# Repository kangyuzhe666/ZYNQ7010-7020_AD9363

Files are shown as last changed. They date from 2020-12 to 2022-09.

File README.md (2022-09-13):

# ZYNQ7010/7020_AD9363/AD9364/AD9361

####  Open source SDR hardware based on ZYNQ+AD936X






[中文](./README_CN.md) 
##  Open source SDR hardware based on ZYNQ+AD936X

## The preliminary development work has been completed and the product has entered the trial production stage. Please contact the email address: 1399109998@qq.com for finished products.
2022-09-13 update
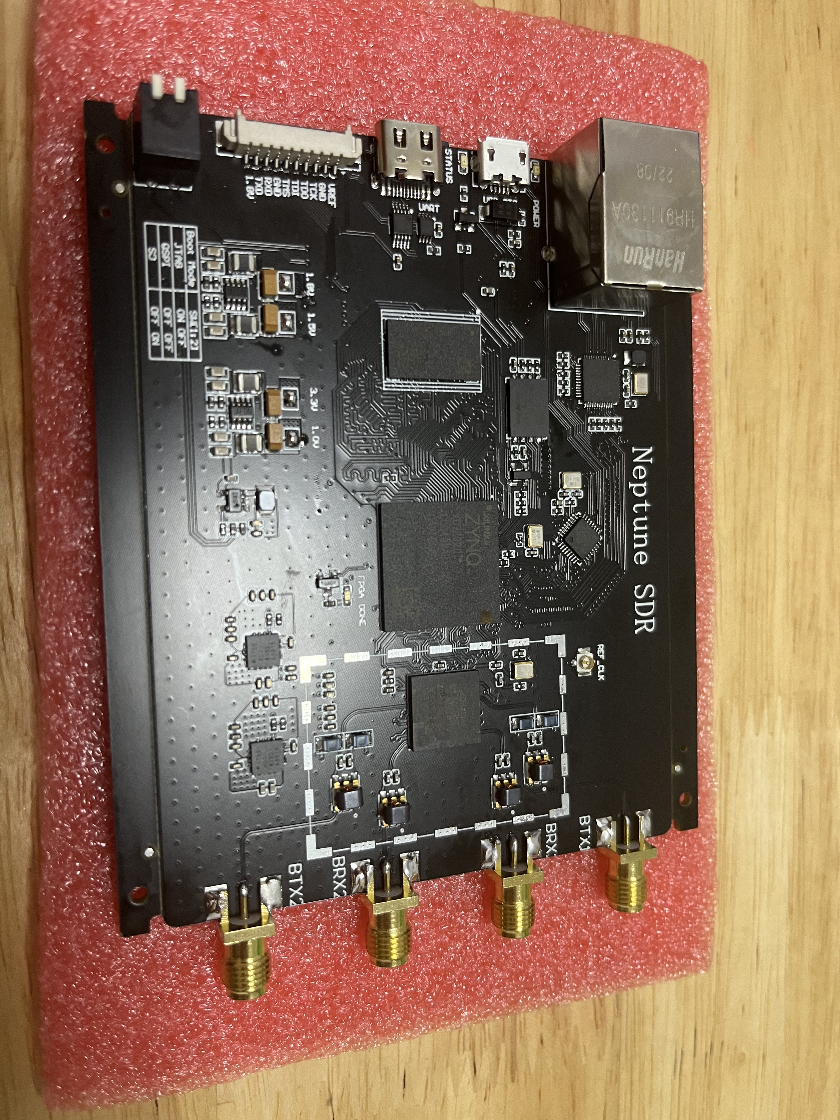
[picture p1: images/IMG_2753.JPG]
a83

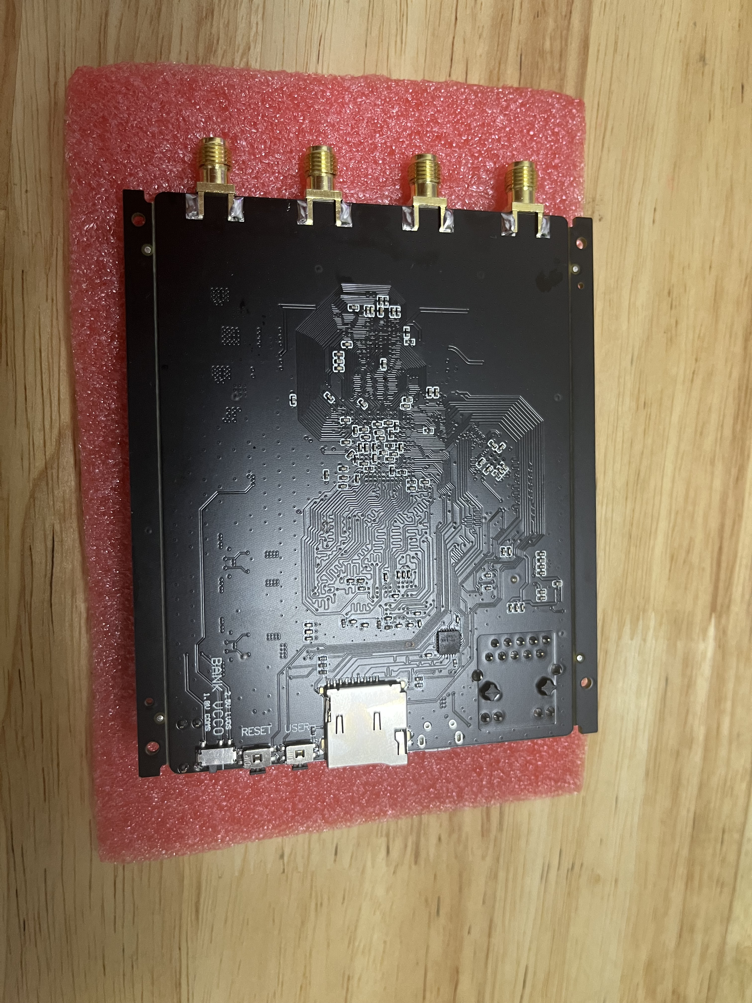
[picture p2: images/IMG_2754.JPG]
a82

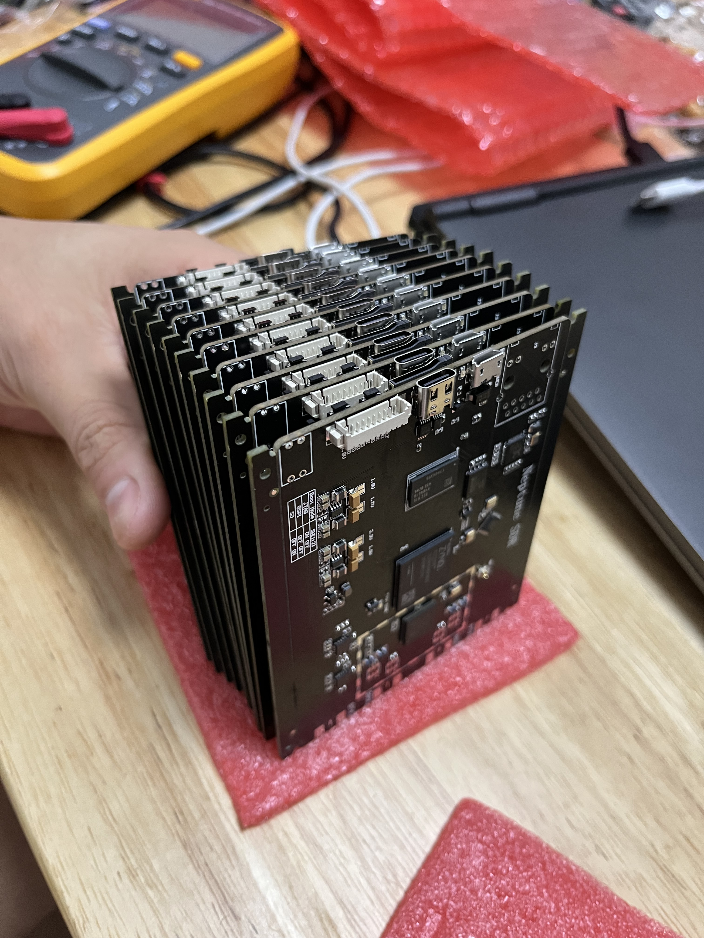
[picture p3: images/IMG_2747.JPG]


## formal support openwifi
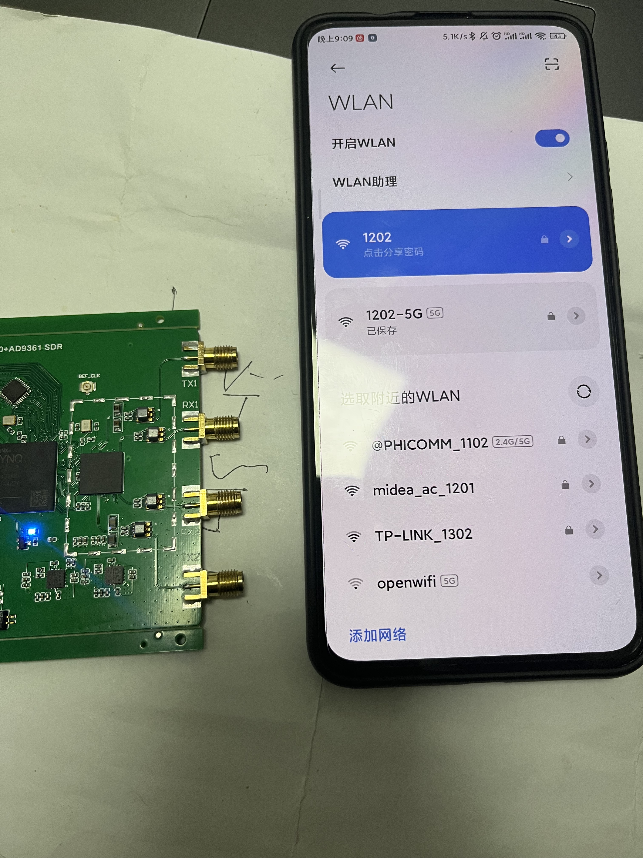
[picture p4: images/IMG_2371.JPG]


openwifi test video
- https://www.bilibili.com/video/BV1hB4y1k7dm?spm_id_from=333.999.list.card_archive.click

Project introduction video:

- https://www.youtube.com/watch?v=Qk-M8yRsKvs 

- https://www.youtube.com/watch?v=xx4MXQSHmCM&t=153s

GSM signals receiver test:
- https://www.youtube.com/watch?v=yFEpSrWW0-w

FM signal receiver test:
- https://www.youtube.com/watch?v=ASb7dLIEmfY

Sine wave signal transmission test:
- https://www.youtube.com/watch?v=bfs_GfULIoA&t=55s

Loopback signal test:
- https://www.youtube.com/watch?v=JOjsKboq0xA

The pluto-sdr firmware transplantation work is all done, flashing the firmware without hacking the system, the default is AD9364.

#### 1. Hardware solution

FPGA: ZYNQ7010/7020 (ZYNQ7010 and ZYNQ7020 can be replaced with each other, if you need more hardware resources, please use ZYNQ7020)

RF: AD9361/AD9363/AD9364 (the three chips can be replaced with each other, the difference lies in the bandwidth. Among them, AD9361 has better performance, try to use the ABCZ ending chip, which is different from BBCZ)

https://ez.analog.com/wide-band-rf-transceivers/design-support/f/q-a/80027/what-is-difference-of-ad9363-abcz-and-bbcz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

AD9363ABCZ Band: 325 MHz to 3.8 GHz

AD9363BBCZ Band: 650 MHz to 2.7 GHz

RAM Memory: DDR3 256M16

USB-PHY: USB3320C

GMAC-PHY: RTL8211E-VL (RTL8211E has two endings, VB and VL, where VB level is 3.3V/2.5V, VL is 1.8V)

QSPI FLASH: W25Q256 32MB

Power supply topology diagram

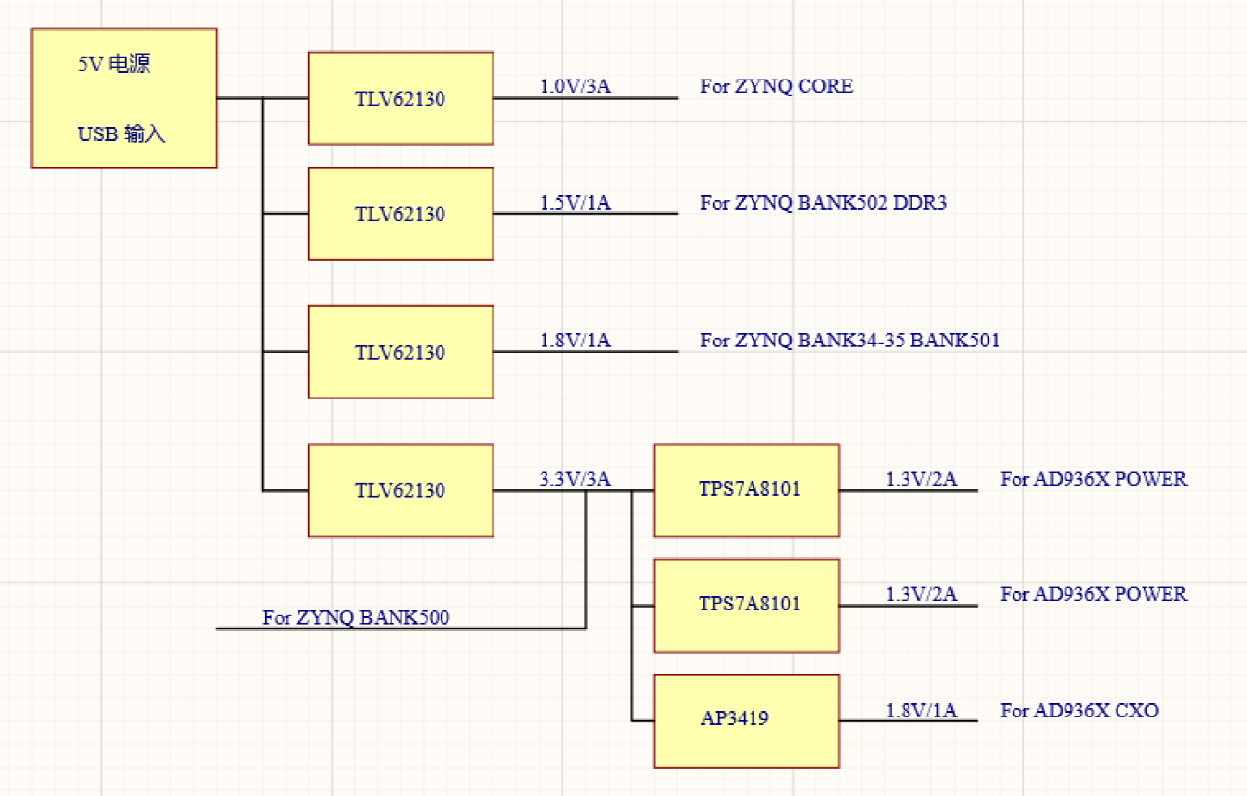
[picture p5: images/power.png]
power


block design

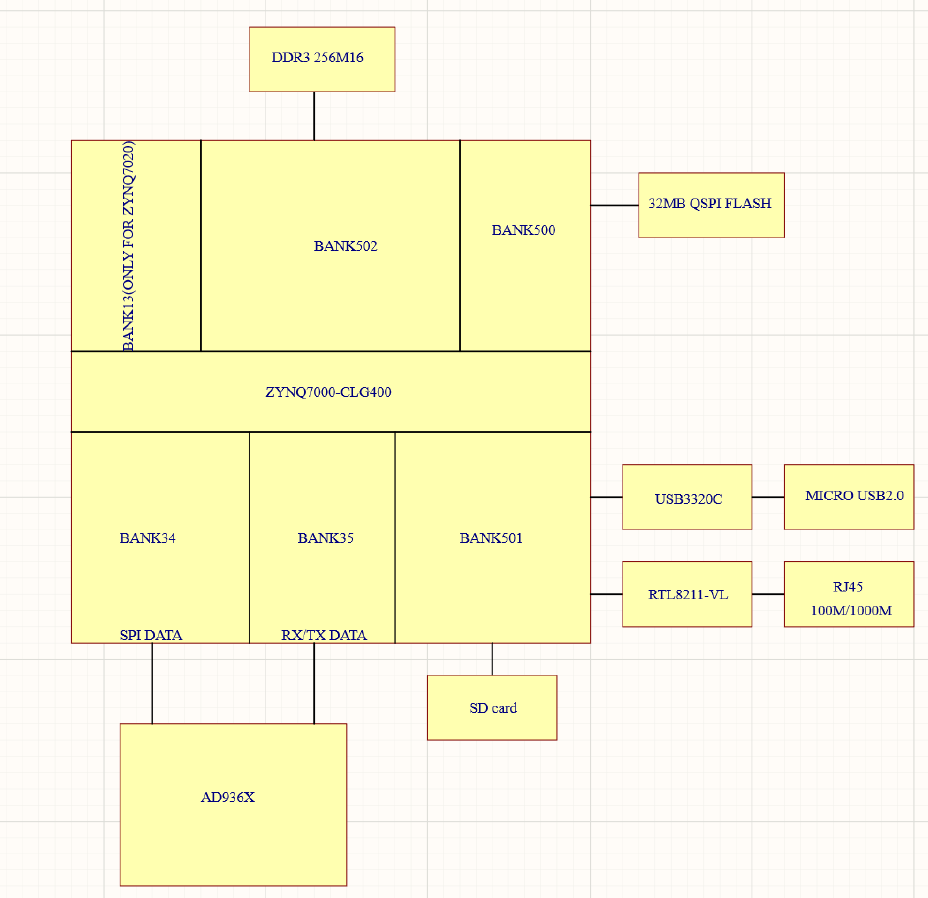
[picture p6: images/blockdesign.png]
blockdesign


##### 2. Software resources

Support Pluto-SDR firmware transplantation, OpenWiFi (ZYNQ7020 FPGA required), support adi official ZED+AD-FMCOMMS2/3/4 related firmware code

#### 3. PCB board design

Design software:  Altium Designer Kicad

Number of layers: 4 layers （signal layer[1]、GND[2]、POWER[3]、signal layer[4]）

Craft: JLC PCB Craft

Impedance: not supported

The impedance version will be tested in March 2021, and the openwifi port is currently undergoing normal transceiver tests.

#### 4. Differences compared to ADALM-PLUTO:

- Support for Zynq-7020 and Zynq-7010 in 400pin BGA package
- Support 2R2T transceiver mode
- 4 layer board to reduce cost
- SD slot for running real Linux distros
- Support Gigabit Ethernet

#### 5. Project display:

This is the PCB rendering

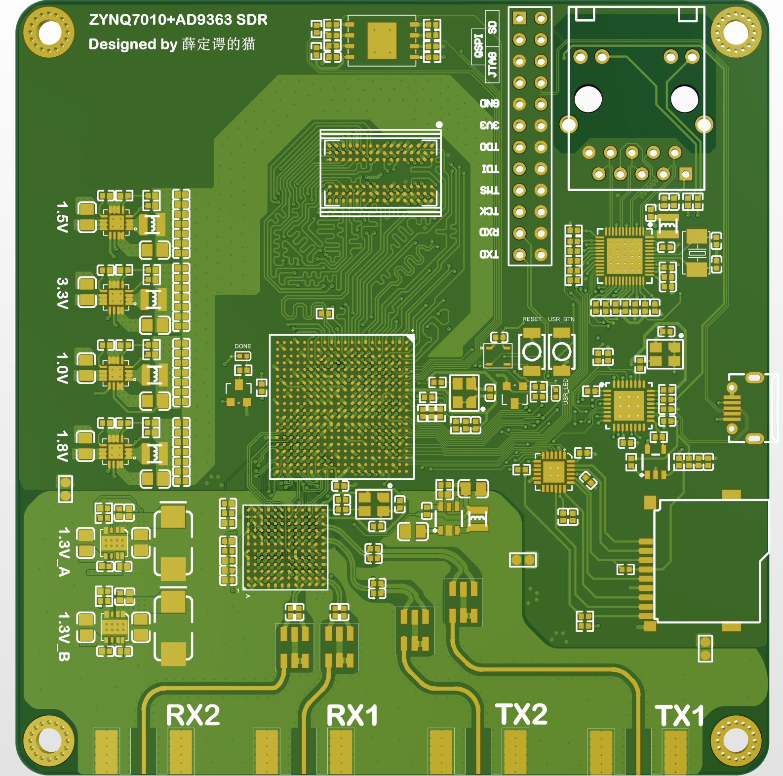
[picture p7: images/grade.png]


This is the physical picture of the PCB

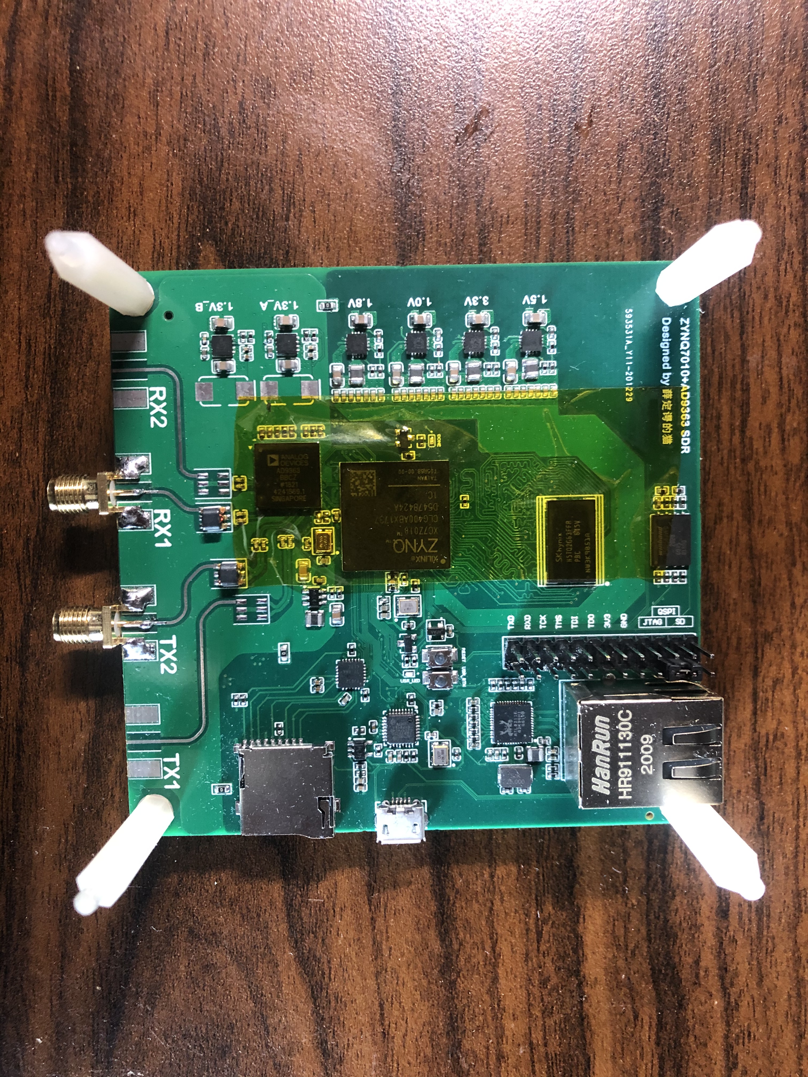
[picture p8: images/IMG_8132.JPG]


This is the details of the PCB RF part

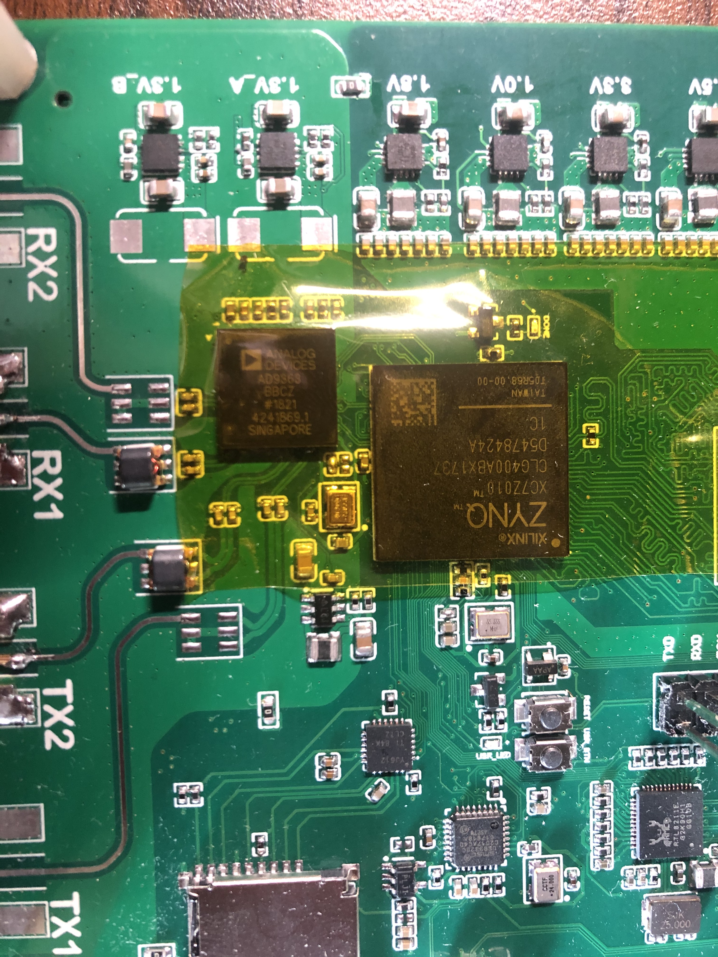
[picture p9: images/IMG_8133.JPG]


Ethernet can work stably at 1000M (using single-arm routing for testing in the figure)

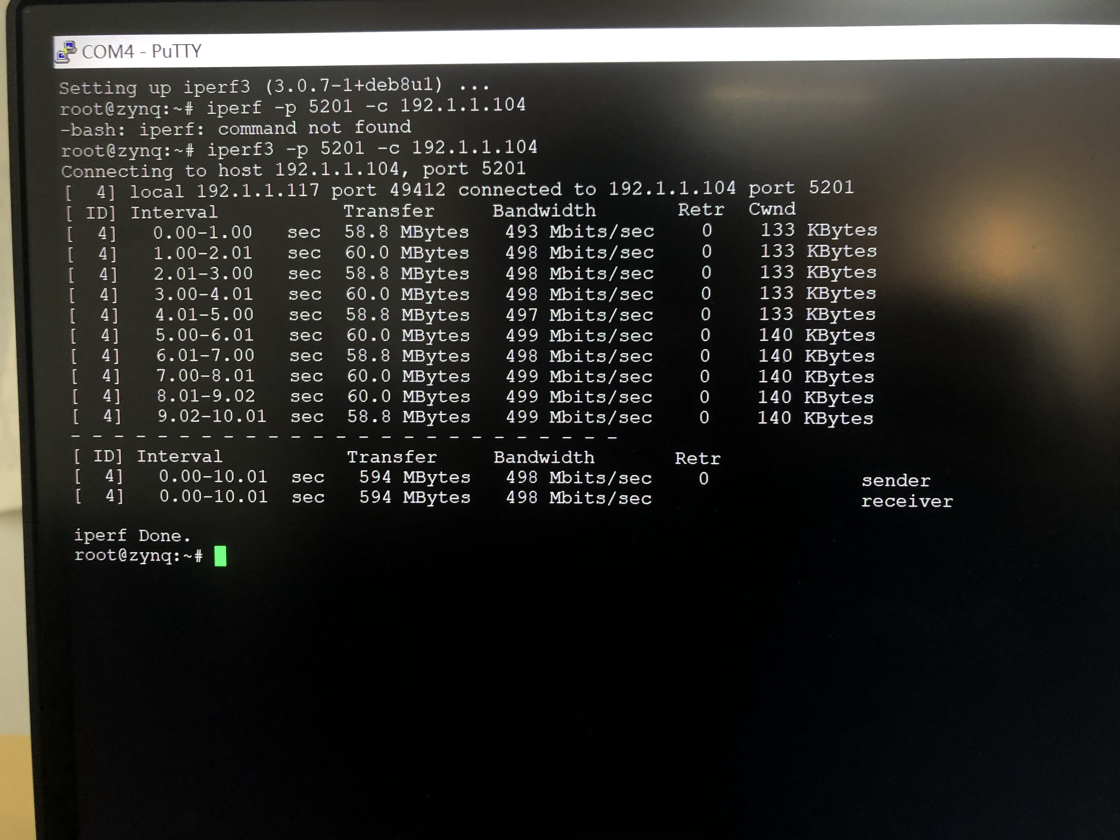
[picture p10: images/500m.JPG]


AD9363 initializes the normal graph using adi no-os test environment

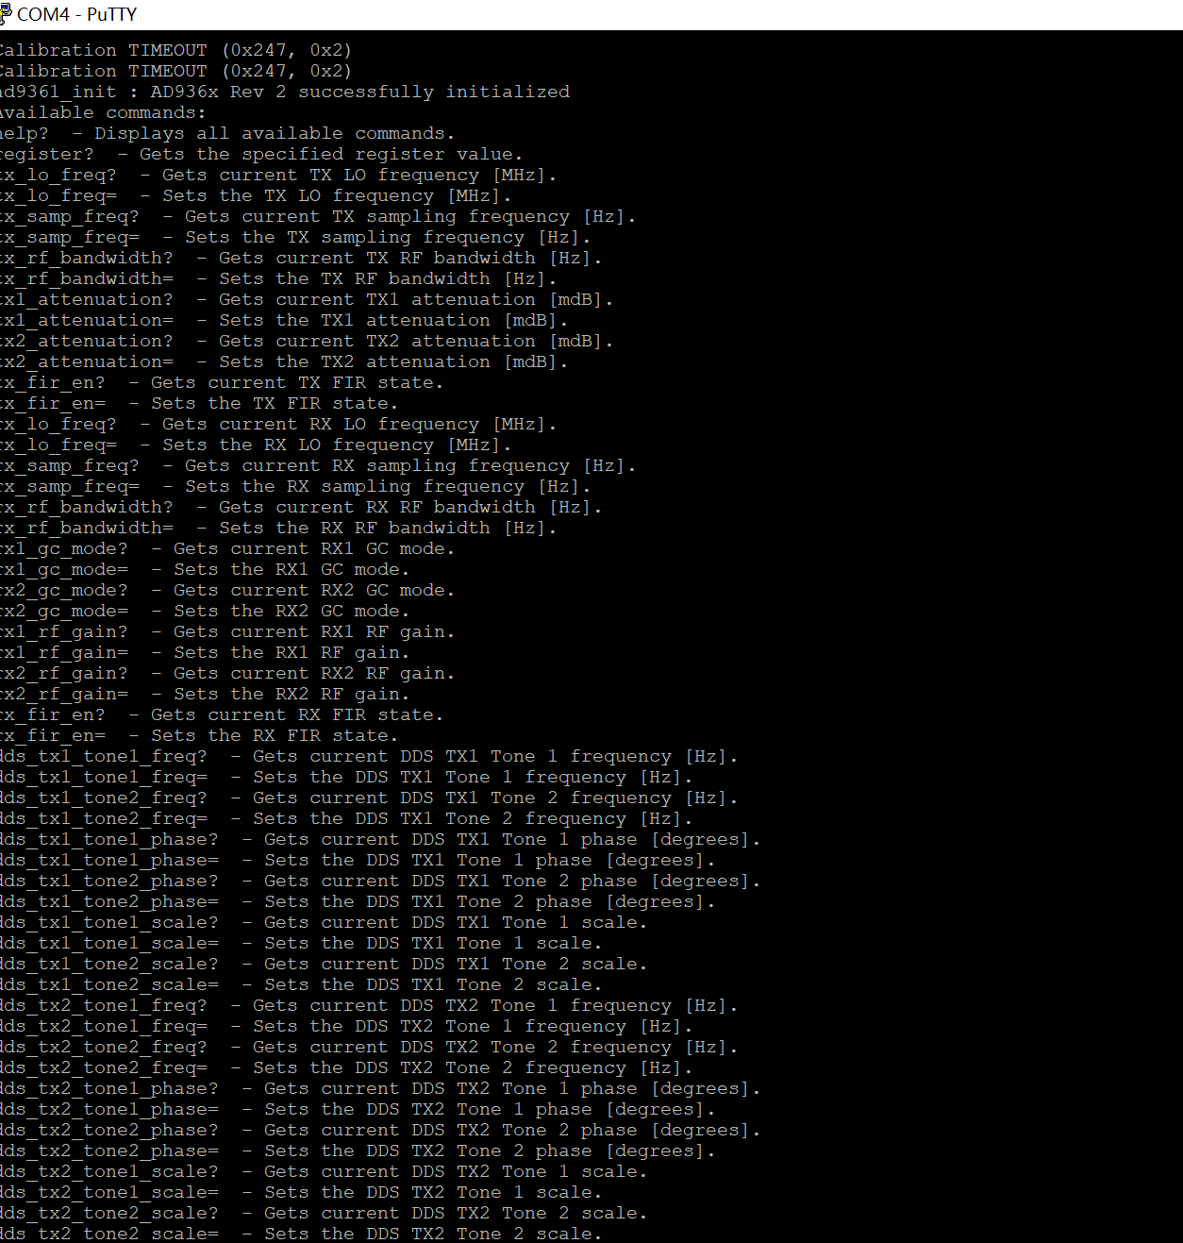
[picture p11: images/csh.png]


Pluto-uboot transplanted successfully

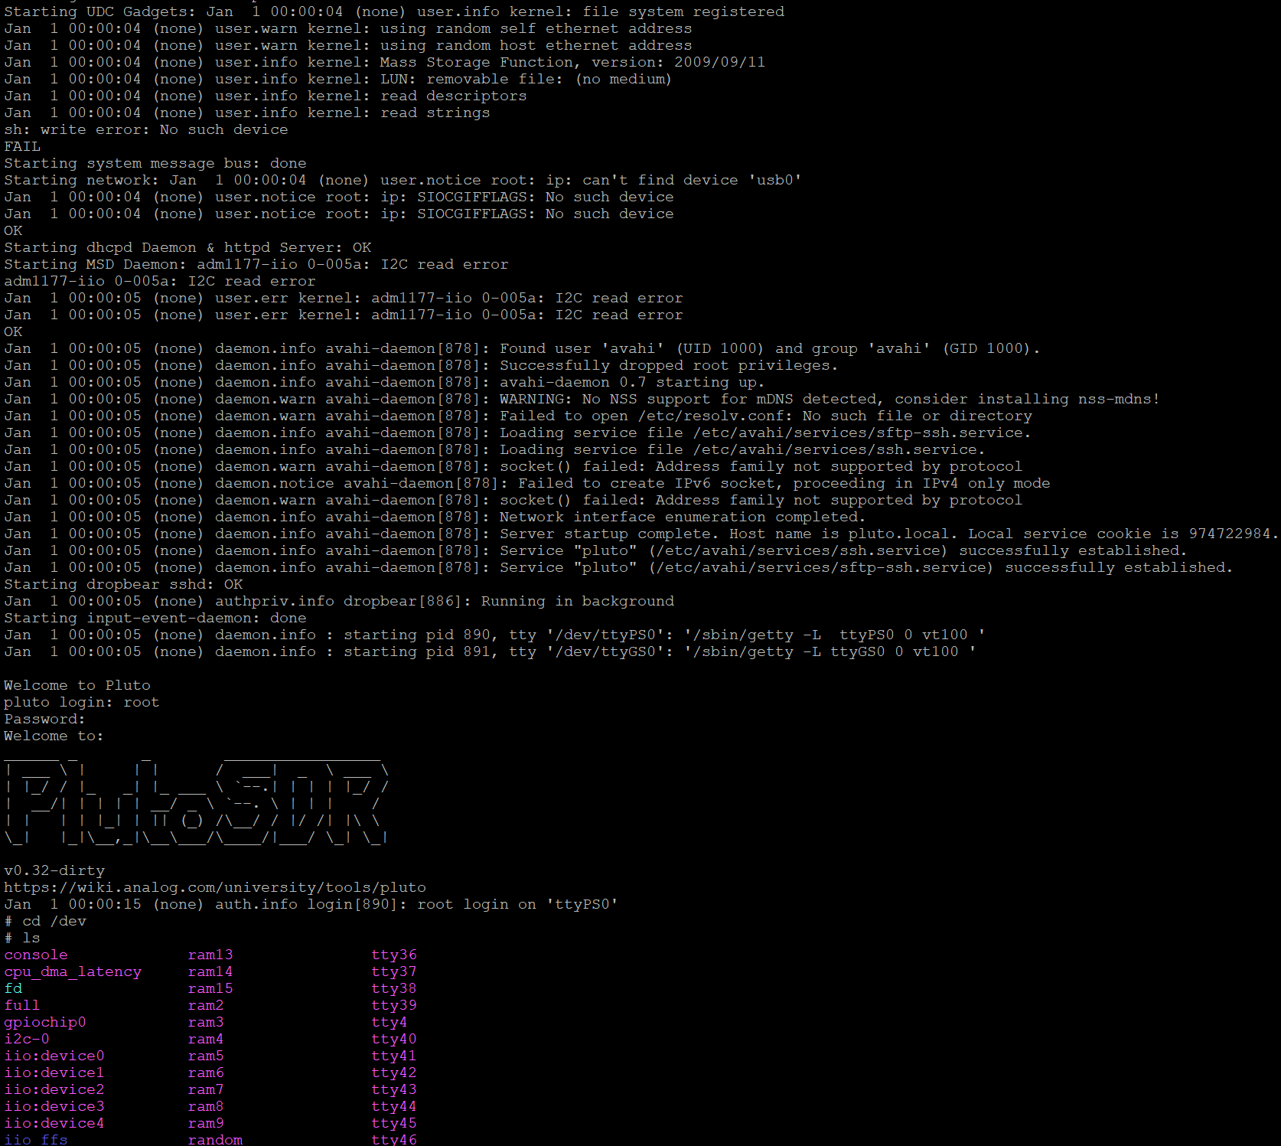
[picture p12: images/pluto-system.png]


Pluto firmware works fine

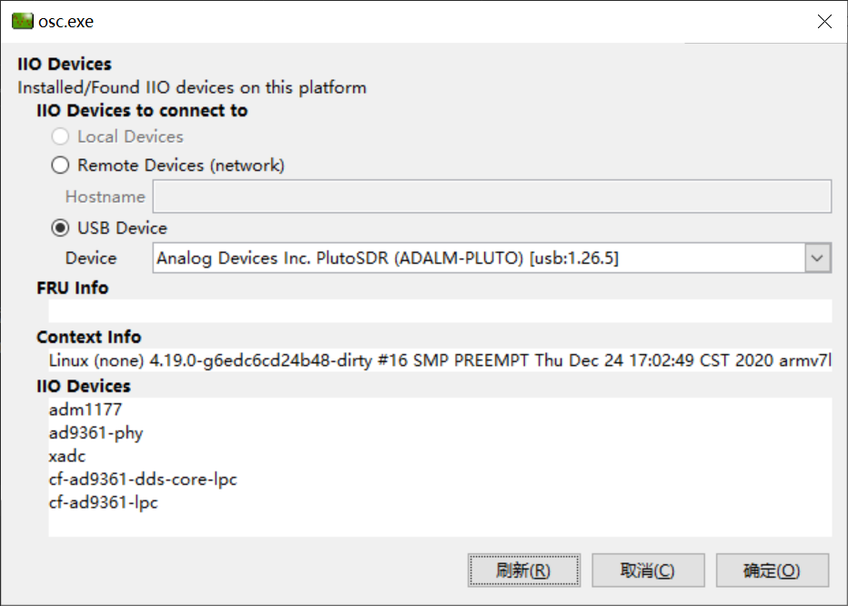
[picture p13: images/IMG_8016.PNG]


Receive GSM signal normally

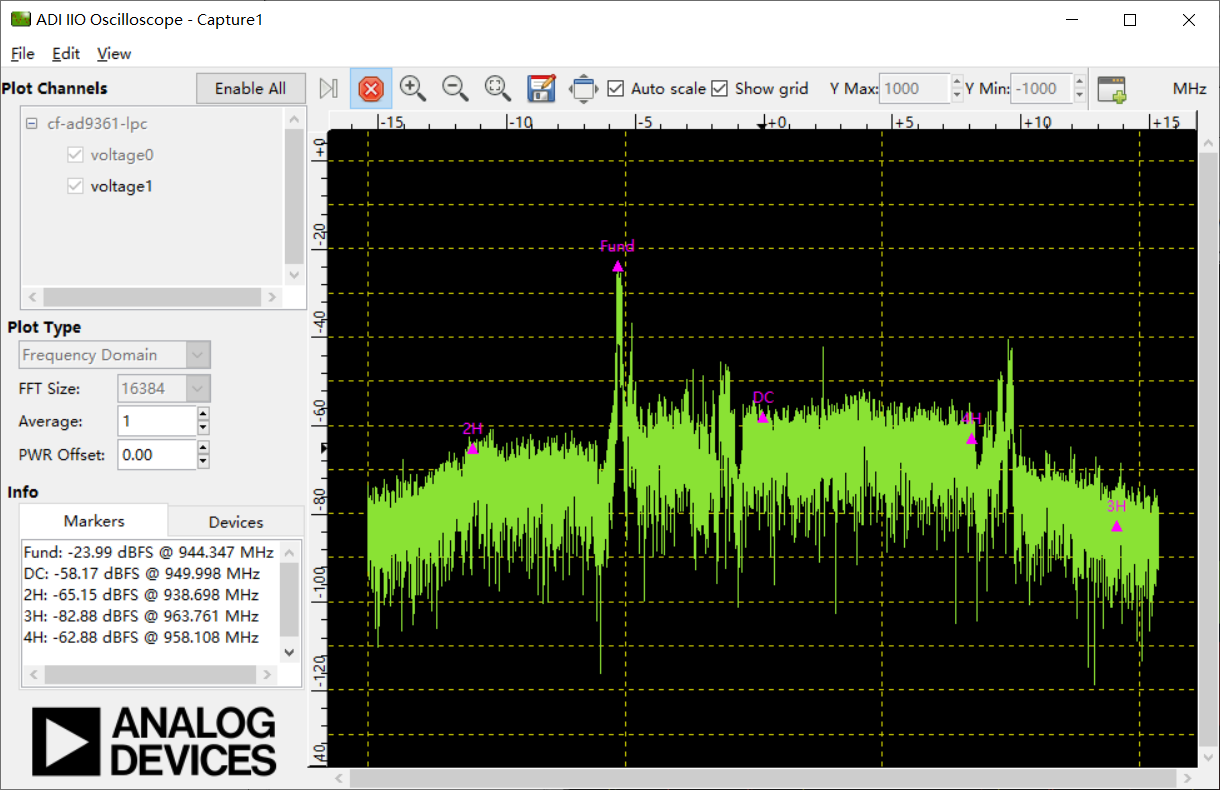
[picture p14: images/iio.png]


Hack into AD9364 to receive FM signal

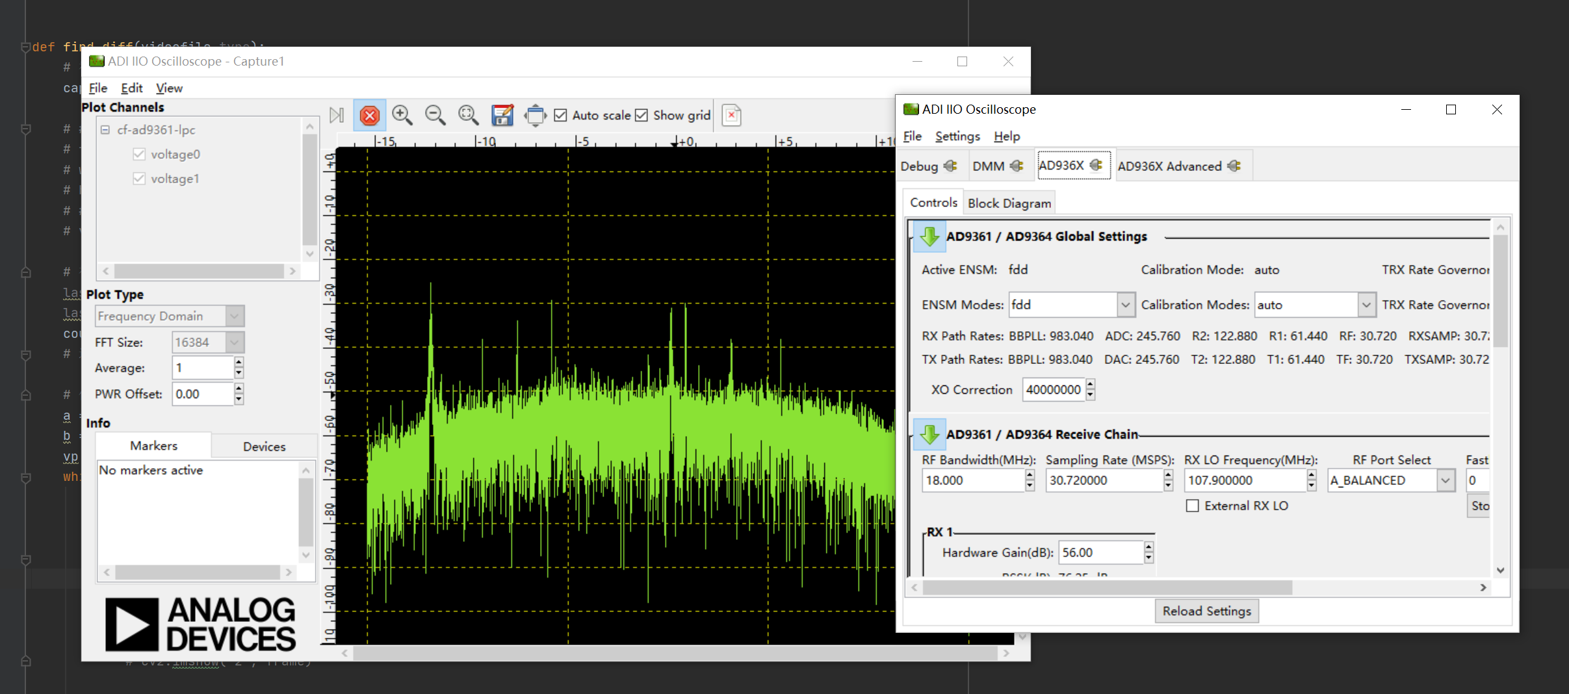
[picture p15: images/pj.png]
pj


Two PCBAs receive and send each other test

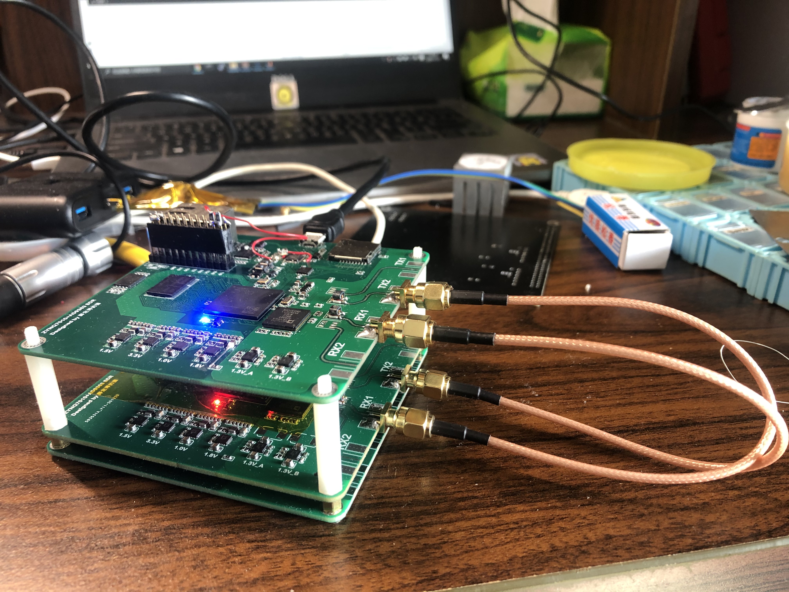
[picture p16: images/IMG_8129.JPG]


PCBAs can be stacked on each other and connected through Gigabit switches and routers

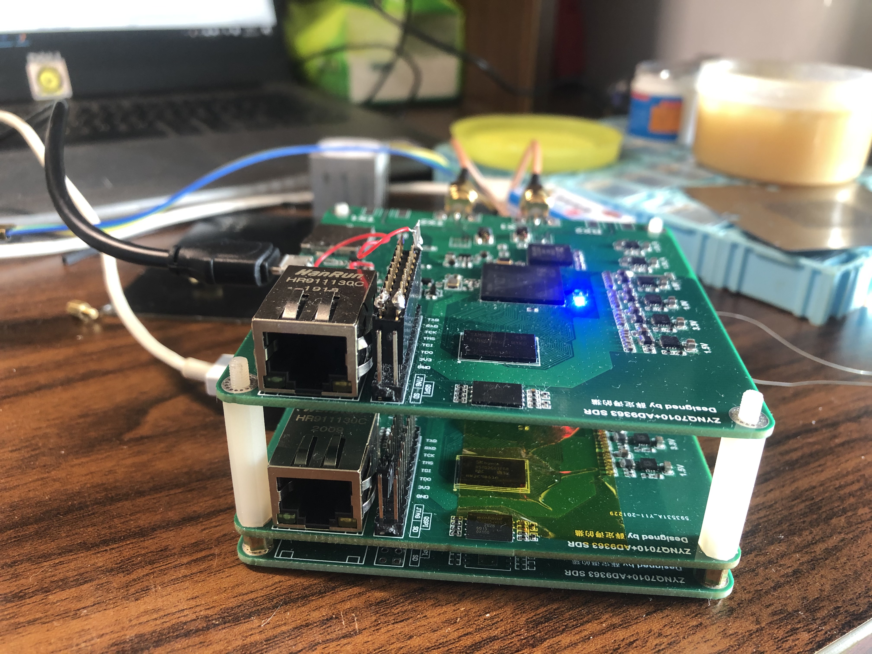
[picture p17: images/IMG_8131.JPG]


Support SDR-SHARP

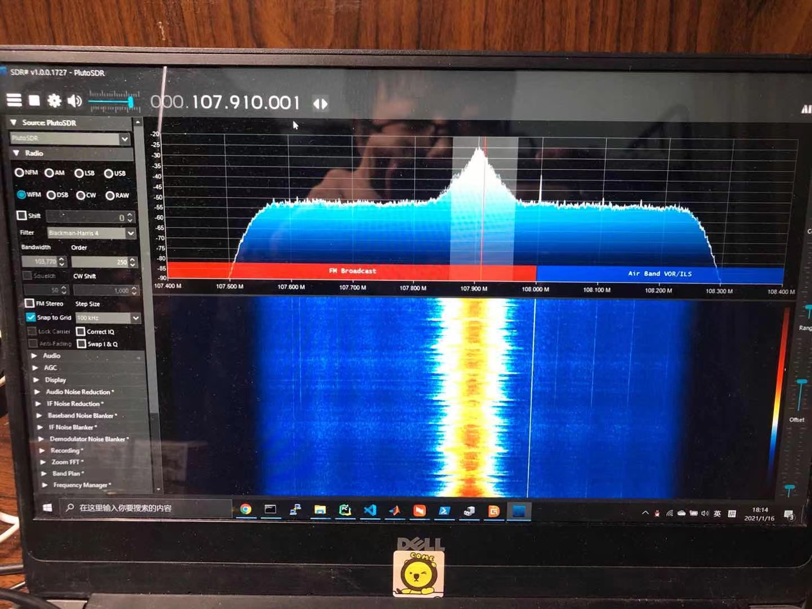
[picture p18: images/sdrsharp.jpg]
sdrsharp


##### 6.TO DO LIST

- Continue to optimize the RF part to reach the adi official demo board indicators
- Impedance design based on four-layer pcb
- To be completed in January-February of 2021, to complete the relevant transplantation work of openwifi
- Design the impedance version in March 2021
- Conduct commercial index tests on the impedance version in April 2021
- When the commercial version is launched at the end of April 2021, it will support adi's official SDR firmware (ADRV9364 packet), openwifi, and openbts openbts, etc.

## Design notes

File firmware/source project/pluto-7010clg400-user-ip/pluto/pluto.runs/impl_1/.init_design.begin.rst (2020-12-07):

<?xml version="1.0"?>
<ProcessHandle Version="1" Minor="0">
    <Process Command=".planAhead." Owner="kyz" Host="" Pid="129447">
    </Process>
</ProcessHandle>

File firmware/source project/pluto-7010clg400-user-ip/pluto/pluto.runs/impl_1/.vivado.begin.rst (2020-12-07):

<?xml version="1.0"?>
<ProcessHandle Version="1" Minor="0">
    <Process Command="vivado" Owner="kyz" Host="" Pid="129406">
    </Process>
</ProcessHandle>

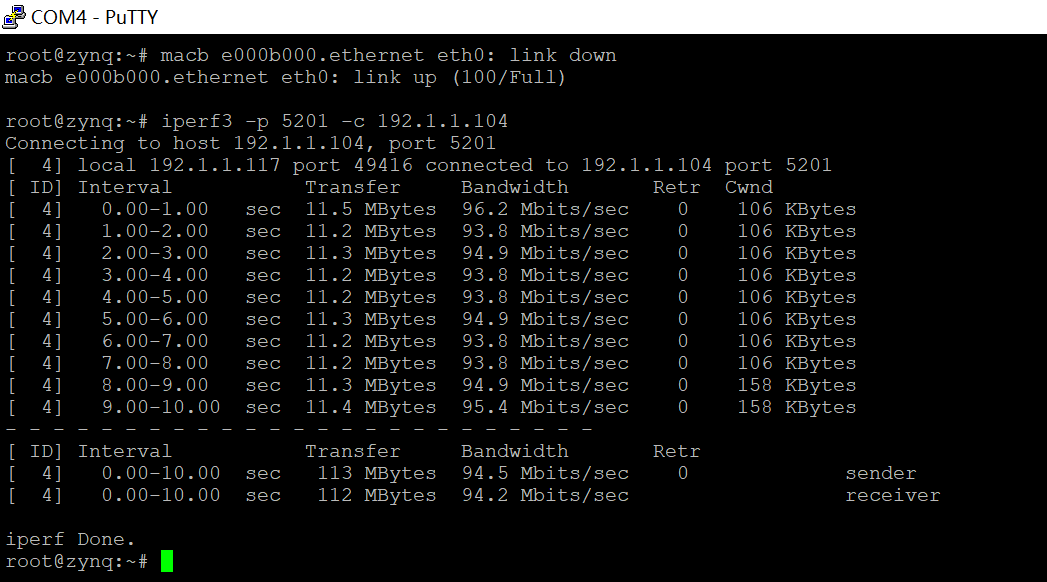
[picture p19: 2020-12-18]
images/eth.png

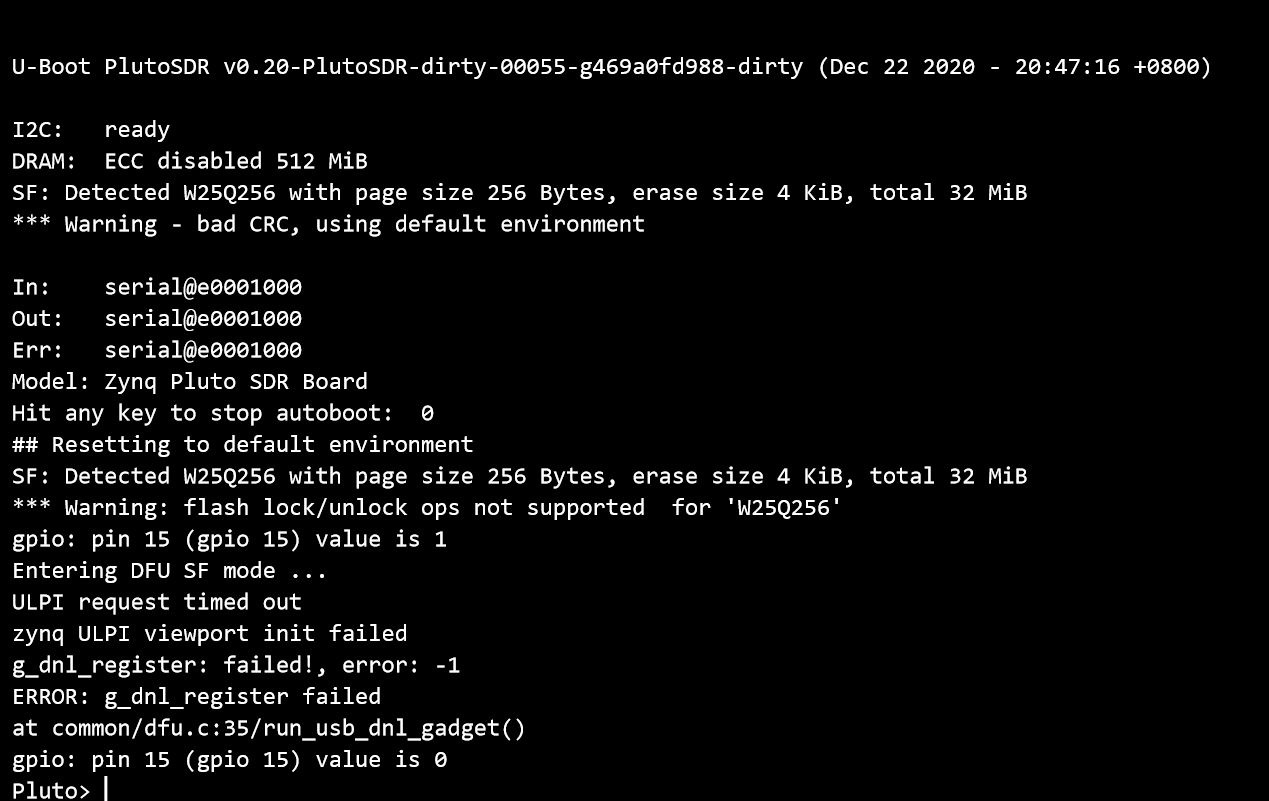
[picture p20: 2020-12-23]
images/pluto.png

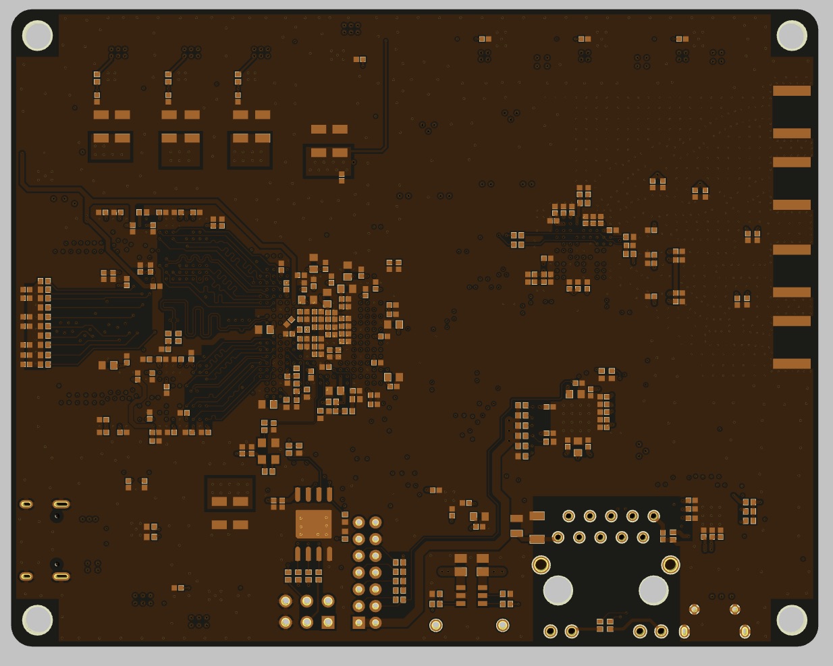
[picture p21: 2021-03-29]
images/a81.PNG

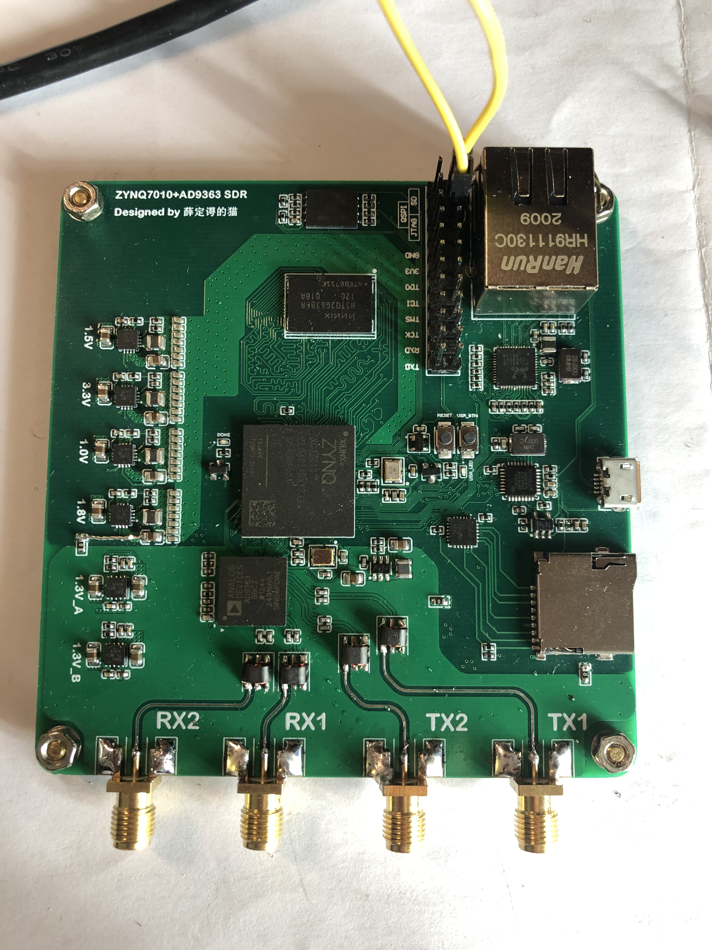
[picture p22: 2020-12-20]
images/wq.JPG

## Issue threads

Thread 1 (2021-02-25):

Max sample rate?

eljuligallego, 2021-02-25:
Hello,
congratulation for the amazing work it looks amazing.

I'm just curious about this because is picture of max transfer with iperf3 you get more or less 95Mbits but it is because the ethernet is configured as 100mbps but the ethernet chip could handle 1gbps.

Also from other pluto-like board with ethernet they stated the bottleneck is in the iio driver but 10Msps could be achieved and from analog specification(2 bytes per sample and IQ baseband) this is about 320mbps. Also the pluto board could get 24MBps with usb2 because usb bottleneck.

it's possible to get gigabit ethernet or is still in progress?.

Thanks,
juli.

kangyuzhe666, 2021-02-26:
Hello, thank you very much for your interest in my project. At present, the development of eth for this project has been completed. Theoretically, it can reach a sampling rate of 19msps (occupying about 700-800mbps bandwidth, please use gigabit link equipment). This project uses rtl8211e to automatically negotiate as a 1000m Ethernet in the system. The relevant firmware has been released [https://github.com/kangyuzhe666/ZYNQ7010-7020_AD9363/releases]
At present, we are further improving the stability of the hardware, and a stable hardware version will be launched in March. At that time, the price of the hardware will be much lower than the same pluto hardware with eth on the market.

Thanks,
yuzhe Kang

eljuligallego, 2021-02-26:
Thanks and please let me know if you get to capture with this throughput 800mbps, no much sdr board can do this, but as far I can understand form the pluto+ creator who just import the pluto firmware to its board(and he uses the same rtl8211 chip):

https://twitter.com/fei666888/status/1354228737491890178

"At present, when the test reaches 10M bandwidth, it will be stuck, which is far from full of Ethernet bandwidth. We analyzed the reason is that ADI's IIO drive efficiency is too low, and time is spent on memory copying."

kangyuzhe666, 2021-02-26:
Hello, thank you very much for your reply. I am not sure about this developer's firmware development on Twitter. ZYNQ7000 has two ARM A9 cores. It can only be limited to about 10M when using one core. The official firmware of pluto only turns on one core by default. Our project uses two A9 cores, so it can meet the sampling rate above 10M, please continue to pay attention to my github dynamics. We will upload more test data in the future. Since I am currently on holiday, I cannot provide too much data to you. Please wait for a while.

eljuligallego, 2021-02-26:
Thanks for your attention.I will stay on tune.

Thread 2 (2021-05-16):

sd card

hitstm32, 2021-05-16:

hitstm32, 2021-05-16:
use for voltage trans?

kangyuzhe666, 2021-05-18:
> use for voltage trans?
Since the signal level of most sd cards is 3.3v, and the io level of bank501 connected to the sd card is 1.8v, in order to make the sd card work normally, txs02612 is added for level conversion

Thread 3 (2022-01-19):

PCB update

mihaly4, 2022-01-19:
Hello,
Are you planning to update PCB files in this repo to latest versions, seen on images?

LavanyaPriya23, 2024-11-27:
Hello,
Can you provide fab notes for the pcb design?

LIMPIX31, 2024-12-21:
Also want to see the updated kicad files to use as a reference in my design

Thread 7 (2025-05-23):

Help, the whole board has no response after power on

X-System-U, 2025-05-23:
After powering on via USB, the tps2051 was not turned on, resulting in a lack of power to the entire board. The voltage between pin 24 and pin 22 of the usb3320 was only 2.1v. I think this may be the reason why the usb3320 did not send a high-level start signal to the tps2051. However, the components were installed according to the schematic diagram. Currently, only the zynq7010 ad9363 and the flash memory chip were not installed.Hope to answer

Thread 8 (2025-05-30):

RFGND resistors vs. ferrite beads & RF Shielding possibilities

Wilmox, 2025-05-30:
Hi! Thank you for making this beautiful open-source SDR!

I am wondering why you have so many **0-Ohm** resistors going from **RFGND** to **GND** (RX6-RX8 & RX13-RX15 in AD9363.SchDoc)? Are these supposed to be placeholders for Ferride beads to minimize high-frequencies going to GND, or are you really soldering **0 Ohms** on them?

The same applies to RX4 (same schematic); is this a placeholder for a **pull-up resistor** or **ferrite bead**? Or also **0 Ohm**?

Last quick question: Do you have a recommended **RF shield** to mitigate any electromagnetic interference coming out of the **AD9363** or the transformers close to it?

Looking forward to any answers!

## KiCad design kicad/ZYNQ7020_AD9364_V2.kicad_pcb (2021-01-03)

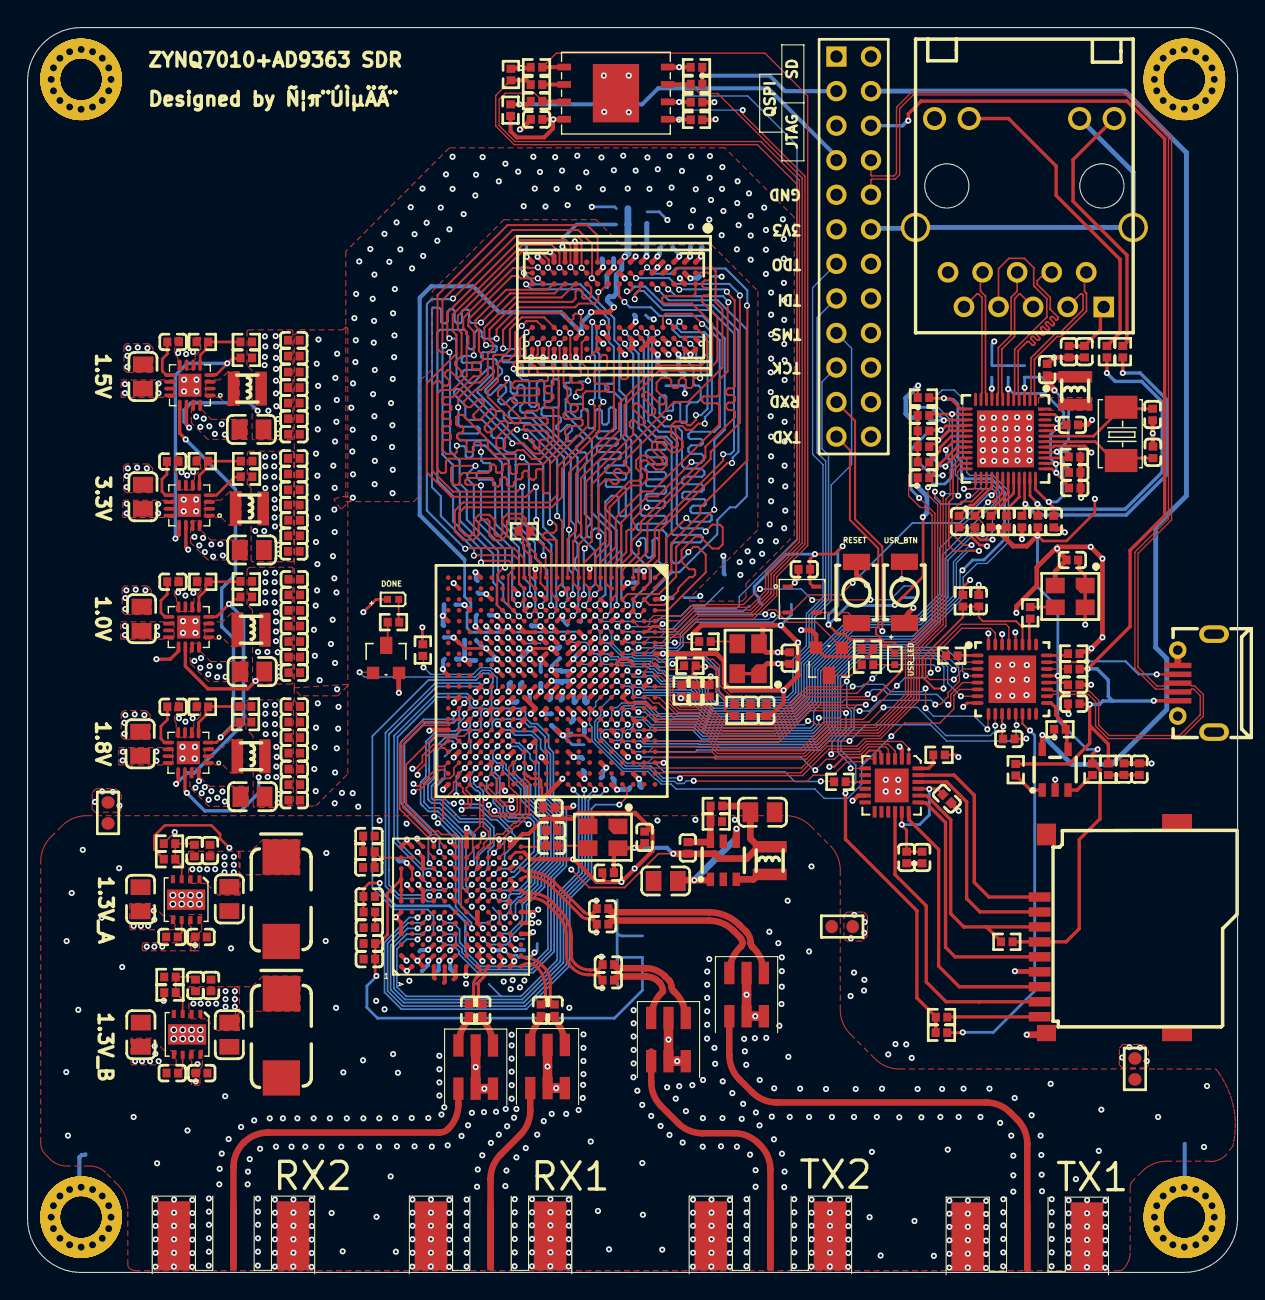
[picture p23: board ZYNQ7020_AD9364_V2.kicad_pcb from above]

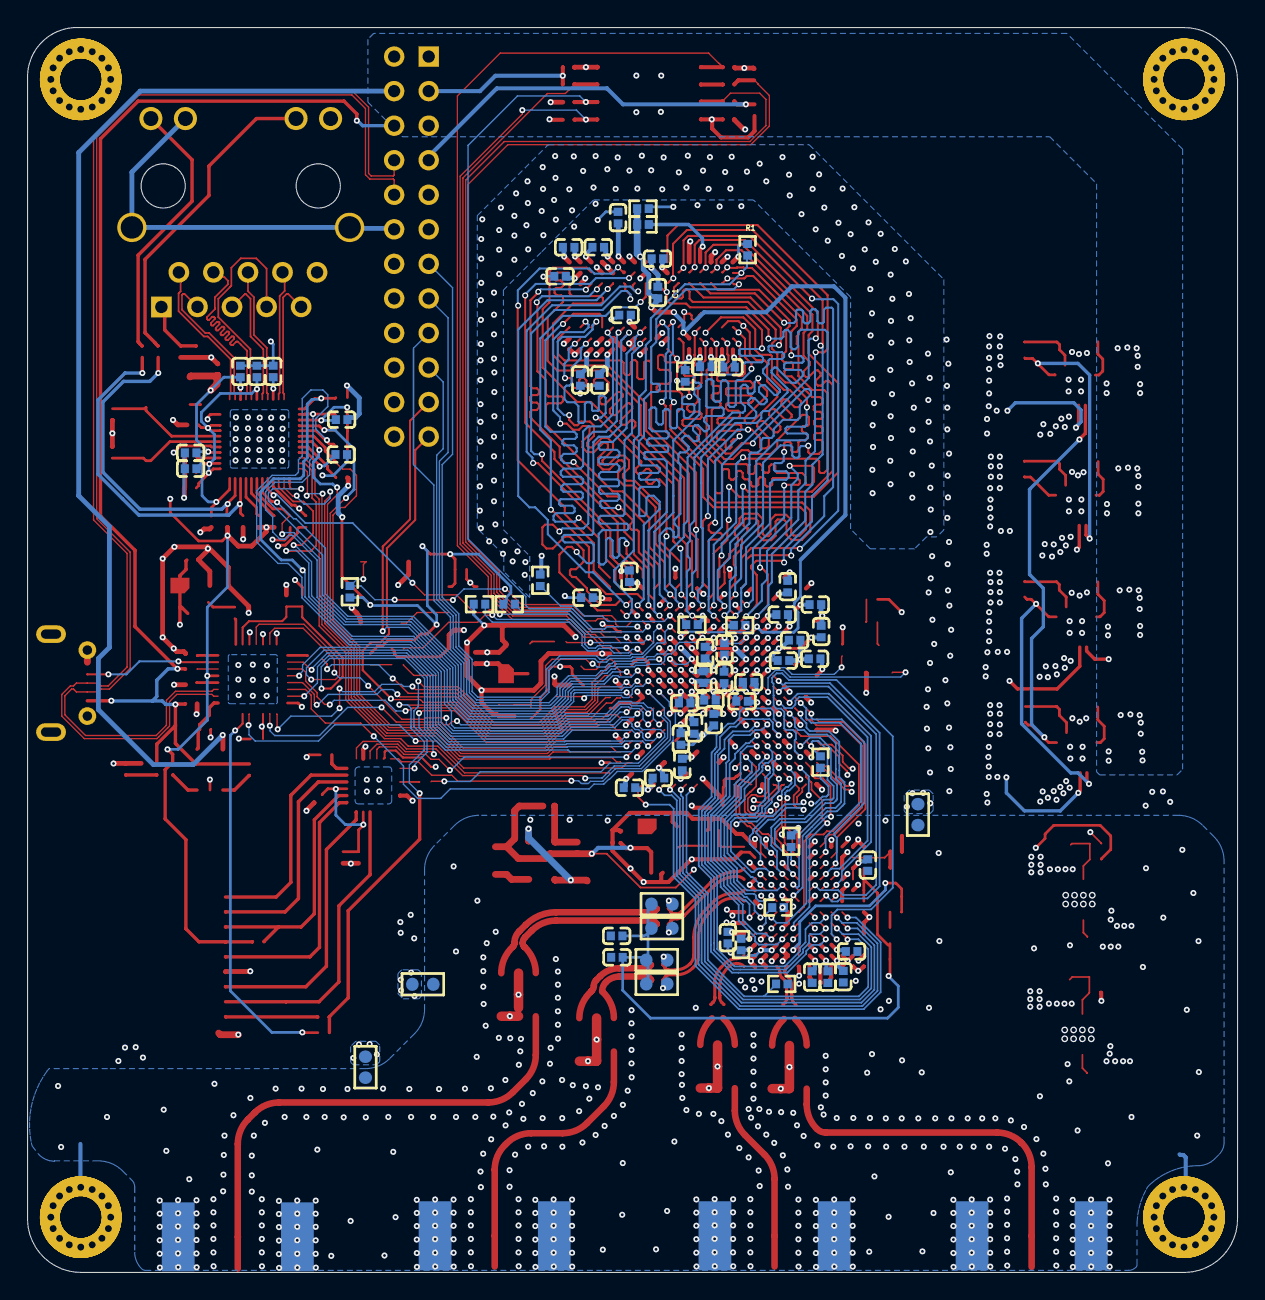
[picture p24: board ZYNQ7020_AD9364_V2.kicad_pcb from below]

Board: 4 copper layers, 89.0 x 91.5 mm, 287 parts (71 on the bottom side), 278 nets.

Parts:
*: W25Q128
C1, C159, C160, C161, C187, C188, C189, C190, C191, C192, C193: 104; CAP
C2, C3, C4, C5, C8, C9, C10, C12, C33, C34, C35, C36, C37, C38, C39, C49, C50, C51, C52, C53, C57, C61, C62, C67, C68, C69, C70, C71, C72, C73, C74, C75, C76, C77, C78, C80, C81, C82, C83, C85, C86, C87, C89, C90, C91, C96, C98, C99, C100, C101, C102, C103, C104, C105, C106, C107, C108, C148, C149, C181, C182, C183: 10¦ÌF; CAP_3
C6, C7, C11, C13, C18, C21, C23, C26, C27, C28: 0.1¦ÌF; CAP_3
C16, C29, C30, C31, C32, C40, C47, C48, C117, C118, C150, C152: 18p; CAP_1
C17, C20, C22, C25: 2.2¦ÌF; CAP_3
C19, C24: 3.3nF; CAP_3
C58, C60, C121, C139, C144: 10¦Ì; CAP_2
C59, C63: 0.001¦Ì; CAP_2
C109, C110, C111, C113, C114, C115, C116, C124, C125, C126, C127, C128, C130, C131, C142: 1¦Ì; CAP_2
C112, C120, C122, C132, C133, C134, C138, C141, C143: 0.1¦Ì; CAP_2
C119: 0.01¦Ì; CAP_2
C129, C135, C136, C137: 4.7¦Ì; CAP_2
C145, C166, C170, C172, C174: 1¦Ì; CAP_1
C146, C151, C175, C177: 0.001¦Ì; CAP_1
CP1, CP3: 22uF; CAP_1
CP2: 22pF; CAP_2
Ct1, Ct2: 3.3nF; CAP_3_3
DONE: LED; LED0
J2: microusb
L1, L2, L3, L4, L6: 2.2uH; INDUCTANCE_1
L5, L7, L8, L9: 330nh; INDUCTANCE
LG1: HR911130C
LP1: 4.7uH; INDUCTANCE
P2: Header 12X2A
Q1, Q2: AO3400
R1, R4, R5, R27, R35, R36, R38, R39, R40, R41, R43, R45, R46, R55, R57, R62, R63: 4.7K; RES
R2, R3: 82R; RES
R6: 240R; RES
R7, R68: 100K; RES
R8, R13, R15, R19, R24, R25, R30, R54, R65, R69, R71: 10K; RES
R9: 4.99K; RES
R10: 18.7K; RES
R11, R47, R49, R50, R51, R52, R53, R56: 20K; RES
R12, R17: 15K; RES
R14: 13K; RES
R16: 56.2K; RES
R18: 18K; RES
R20: 80.6R; RES
R21, R22: 6.25K; RES
R23, R64, R67: 0R; RES
R26: 2.49K; RES
R28, R29, R37, R42, R58, R76: 33R; RES
R31, R32, R70: 330R; RES
R33, R34: 1.5K; RES
R44: 8.06K; RES
R48, R66: 1K; RES
R59, R60, R61: 470R; RES
R72: 40.2R; RES
R73, R74: 1R; RES_1
R75: 14.3K; RES_1
RESET: SW-PB
RP1: 10K; RES_1
RP2: 20K; RES_1
RX1, RX2: JCCEM001
RX4, RX5, RX6, RX7, RX8, RX10, RX13, RX14, RX15, RX22: 0R; RES_1
T1, T2, T3, T4: TCM1-63AX+
TU1: TPS2051BDBVR
TX1, TX2: JCCEM001
U1: XC7Z010-CLG400
U2: MT41J64M16JT-187EG; DDR3
U3: RTL8211E-VB-CG
U4: USB3320C
U5: AD9363
U6, U7, U8, U9: TLV62130
U11, U12: TPS7A8101
U13: TCM811TE
UP1: AP3419
USD1: TXS02612RTWR
USR_BTN: SW-PB
USR_LED: LED; LED0
X1: 25M; XTAL-2
X2: 33.333MHz; XTAL-4
X3: 24MHz; XTAL-4
X4: 40MHz; XTAL-4
tf1: TF-SD

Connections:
1P3_TX: C58.1, C59.2, C60.1, C63.2, L5.1, L7.1, L8.1, L9.1, U5.A7, U5.A8, U5.A9, U5.A10
AD9361_CLKOUT: U1.W18, U5.J6
AD9361_RST: RX4.1, U1.R19, U5.K5
ADVDD10: C124.1, C125.1, C126.1, C127.2, C128.2, C130.2, C131.2, L6.2, U3.3, U3.9, U3.28, U3.36, U3.40
CB: *.6, R58.1
CTRL_IN0: U1.G20, U5.C5
CTRL_IN1: U1.D20, U5.C6
CTRL_IN2: U1.F20, U5.D6
CTRL_IN3: U1.H20, U5.D5
CTRL_OUT0: U1.V17, U5.D4
CTRL_OUT1: U1.T14, U5.E4
CTRL_OUT2: U1.T15, U5.E5
CTRL_OUT3: U1.P14, U5.E6
CTRL_OUT4: U1.U14, U5.F6
CTRL_OUT5: U1.U15, U5.F5
CTRL_OUT6: U1.T19, U5.F4
CTRL_OUT7: U1.V18, U5.G4
DATA_CLK_N: U1.U19, U5.H11
DATA_CLK_P: U1.U18, U5.G11
DDR3_A0: U1.N2, U2.N3
DDR3_A1: U1.K2, U2.P7
DDR3_A2: U1.M3, U2.P3
DDR3_A3: U1.K3, U2.N2
DDR3_A4: U1.M4, U2.P8
DDR3_A5: U1.L1, U2.P2
DDR3_A6: U1.L4, U2.R8
DDR3_A7: U1.K4, U2.R2
DDR3_A8: U1.K1, U2.T8
DDR3_A9: U1.J4, U2.R3
DDR3_A10: U1.F5, U2.L7
DDR3_A11: U1.G4, U2.R7
DDR3_A12: U1.E4, U2.N7
DDR3_A13: U1.D4, U2.T3
DDR3_A14: U1.F4, U2.T7
DDR3_BA0: U1.L5, U2.M2
DDR3_BA1: U1.R4, U2.N8
DDR3_BA2: U1.J5, U2.M3
DDR3_CAS: U1.P5, U2.K3
DDR3_CKE: U1.N3, U2.K9
DDR3_CK_N: R20.2, U1.M2, U2.K7
DDR3_CK_P: R20.1, U1.L2, U2.J7
DDR3_CS: U1.N1, U2.L2
DDR3_DM0: U1.A1, U2.E7
DDR3_DM1: U1.F1, U2.D3
DDR3_DQ0: U1.C3, U2.E3
DDR3_DQ1: U1.B3, U2.F7
DDR3_DQ2: U1.A2, U2.F2
DDR3_DQ3: U1.A4, U2.F8
DDR3_DQ4: U1.D3, U2.H3
DDR3_DQ5: U1.D1, U2.H8
DDR3_DQ6: U1.C1, U2.G2
DDR3_DQ7: U1.E1, U2.H7
DDR3_DQ8: U1.E2, U2.D7
DDR3_DQ9: U1.E3, U2.C3
DDR3_DQ10: U1.G3, U2.C8
DDR3_DQ11: U1.H3, U2.C2
DDR3_DQ12: U1.J3, U2.A7
DDR3_DQ13: U1.H2, U2.A2
DDR3_DQ14: U1.H1, U2.B8
DDR3_DQ15: U1.J1, U2.A3
DDR3_DQS0_N: U1.B2, U2.G3
DDR3_DQS0_P: U1.C2, U2.F3
DDR3_DQS1_N: U1.F2, U2.B7
DDR3_DQS1_P: U1.G2, U2.C7
DDR3_ODT: U1.N5, U2.K1
DDR3_RAS: U1.P4, U2.J3
DDR3_RESET: R1.1, U1.B4, U2.T2
DDR3_VREF: C1.1, R4.1, R5.2, U1.H6, U1.P6, U2.H1, U2.M8
DDR3_WE: U1.M5, U2.L3
ENABLE: U1.V15, U5.G6
EN_AGC: U1.W19, U5.G5
ETH_MDC: U1.C10, U3.30
ETH_MDIO: R34.2, U1.C11, U3.31
ETH_RXCK: U1.B17, U3.19
ETH_RXCTL: R36.2, U1.D13, U3.13
ETH_RXD0: R41.1, U1.D11, U3.14
ETH_RXD1: R39.1, U1.A16, U3.16
ETH_RXD2: R43.1, U1.F15, U3.17
ETH_RXD3: R45.1, U1.A15, U3.18
ETH_TXCK: U1.A19, U3.22
ETH_TXCTL: U1.F14, U3.27
ETH_TXD0: U1.E14, U3.23
ETH_TXD1: U1.B18, U3.24
ETH_TXD2: U1.D10, U3.25
ETH_TXD3: U1.A17, U3.26
FB_CLK_N: RX22.2, U1.U17, U5.G10
FB_CLK_P: U1.T16, U5.F10
FPGA_DONE: Q1.1, U1.R11
FPGA_TCK: P2.10, U1.F9
FPGA_TDI: P2.8, U1.G6
FPGA_TDO: P2.7, U1.F6
FPGA_TMS: P2.9, U1.J6
GND: *.4, C1.2, C2.1, C3.1, C4.1, C5.1, C6.1, C7.1, C8.1, C9.1, C10.1, C11.1, C12.1, C13.1, C33.1, C34.1, C35.1, C36.1, C37.1, C38.1, C39.1, C49.1, C50.1, C51.1, C52.1, C53.1, C57.1, C61.1, C62.1, C67.1, C68.1, C69.1, C70.1, C71.1, C72.1, C73.1, C74.1, C75.1, C76.1, C77.1, C78.1, C80.1, C81.2, C82.1, C83.1, C85.1, C86.1, C87.1, C89.1, C90.1, C91.1, C96.1, C98.2, C99.2, C100.2, C101.2, C102.2, C103.2, C104.2, C105.2, C106.2, C107.2, C108.2, C109.1, C110.1, C111.2, C112.2, C113.1, C114.1, C115.1, C116.1, C117.2, C118.2, C119.1, C120.2, C121.1, C122.2, C124.2, C125.2, C126.2, C127.1, C128.1, C129.2, C130.1, C131.1, C132.2, C133.2, C134.2, C135.2, C136.2, C137.2, C138.2, C139.2, C141.2, C148.2, C149.2, C159.1, C160.1, C161.1, C181.2, C182.2, C183.2, C187.1, C188.1, C189.1, C190.1, C191.1, C192.1, C193.1, J2.5, J2.6, J2.7, J2.8, J2.9, LG1.12, LG1.P10, LG1.SHIELD0, LG1.SHIELD1, P2.3, P2.5, P2.18, P2.19, P2.20, P2.21, P2.22, P2.23, P2.24, Q1.2, Q2.2, R1.2, R2.1, R5.1, R6.2, R11.2, R12.2, R17.2, R18.2, R26.2, R28.2, R36.1, R40.1, R44.2, R49.1, R51.1, R53.1, R54.2, R56.1, R62.1, R65.2, R69.2, RESET.1, RX6.2, RX7.2, RX8.2, RX13.2, RX14.2, RX15.2, TU1.2, U1.A8, U1.A18, U1.B1, U1.B11, U1.C4, U1.C9, U1.C14, U1.D17, U1.E10, U1.E20, U1.F3, U1.F7, U1.F10, U1.G10, U1.G12, U1.G16, U1.H7, U1.H9, U1.H11, U1.H13, U1.H19, U1.J2, U1.J8, U1.J10, U1.J12, U1.K5, U1.K7, U1.K10, U1.K11, U1.K13, U1.K15, U1.L8, U1.L9, U1.L12, U1.L18, U1.M1, U1.M7, U1.M9, U1.M10, U1.M11, U1.M13, U1.N4, U1.N8, U1.N10, U1.N12, U1.N14, U1.P7, U1.P9, U1.P11, U1.P13, U1.P17, U1.R8, U1.R12, U1.R20, U1.T3, U1.T7, U1.T13, U1.U6, U1.U16, U1.V9, U1.V19, U1.W2, U1.W12, U1.Y5, U1.Y15, U2.A9, U2.B1, U2.B3, U2.B9, U2.D1, U2.D8, U2.E1, U2.E2, U2.E8, U2.F9, U2.G1, U2.G8, U2.G9, U2.J2, U2.J8, U2.M1, U2.M9, U2.P1, U2.P9, U2.T1, U2.T9, U3.0, U3.47, U4.0, U6.6, U6.7, U6.8, U6.15, U6.16, U6.20, U7.6, U7.7, U7.8, U7.15, U7.16, U7.20, U8.6, U8.7, U8.8, U8.15, U8.16, U8.20, U9.6, U9.7, U9.8, U9.15, U9.16, U9.20, U13.1, USD1.2, USD1.11, USD1.25, USR_BTN.1, X2.2, X3.2, tf1.6, tf1.10
NetC6_2: C6.2, U6.9
NetC7_2: C7.2, U7.9
NetC11_2: C11.2, U8.9
NetC13_2: C13.2, U9.9
NetC19_1: C19.1, R21.2, R24.1, U11.3
NetC24_1: C24.1, R22.2, R25.1, U12.3
NetC27_2: C27.2, U11.6
NetC28_2: C28.2, U12.6
NetC111_1: C111.1, C112.1, LG1.P1
NetC117_1: C117.1, U3.43, X1.1
NetC118_1: C118.1, U3.42, X1.2
NetC119_2: C119.2, R28.1, R29.1, U1.E11
NetC129_1: C129.1, U4.20
NetC135_1: C135.1, C136.1, R64.1
NetC142_1: C142.1, R73.2
NetC145_2: C145.2, R74.1
NetC146_2: C146.2, R73.1, U5.G2, U5.G3
NetC148_1: C148.1, C149.1, R23.2, U1.G8
NetC150_2: C150.2, C152.1, U5.M12
NetC151_2: C151.2, R74.2, U5.A11, U5.B11
NetC152_2: C152.2, X4.3
NetCP2_2: CP2.2, RP1.1, RP2.2, UP1.6
NetDONE_2: DONE.2, R61.2
NetL1_1: L1.1, U6.1, U6.2, U6.3
NetL2_1: L2.1, U7.1, U7.2, U7.3
NetL3_1: L3.1, U8.1, U8.2, U8.3
NetL4_1: L4.1, U9.1, U9.2, U9.3
NetLG1_11: LG1.11, R32.2
NetLG1_13: LG1.13, R31.2
NetLP1_1: LP1.1, UP1.3
NetP2_2: P2.2, R52.1, R54.1
NetP2_4: P2.4, R48.2, R50.1
NetQ1_3: Q1.3, R61.1
NetQ2_3: Q2.3, R60.1
NetR2_2: R2.2, U1.H5
NetR3_2: R3.2, U1.G5
NetR6_1: R6.1, U2.L8
NetR9_2: R9.2, R11.1, U6.5
NetR10_2: R10.2, R12.1, U7.5
NetR14_2: R14.2, R17.1, U8.5
NetR15_2: R15.2, U9.4
NetR16_2: R16.2, R18.1, U9.5
NetR26_1: R26.1, U3.39
NetR27_1: R27.1, U3.32
NetR30_2: R30.2, U1.B10
NetR37_2: R37.2, X2.3
NetR38_2: R38.2, U3.20
NetR42_2: R42.2, U4.1
NetR44_1: R44.1, U4.24
NetR55_2: R55.2, U1.R10
NetR57_2: R57.2, U1.L6
NetR60_2: R60.2, USR_LED.2
NetR62_2: R62.2, USD1.24
NetR63_2: R63.2, USD1.20, tf1.3
NetR67_2: R67.2, TU1.1
NetR68_1: R68.1, TU1.3
NetR70_1: R70.1, tf1.9
NetR72_1: R72.1, USD1.9
NetR75_1: R75.1, U5.L4
NetR76_2: R76.2, X3.3
NetRESET_2: RESET.2, U13.3
NetRX1_1: RX1.1, T1.3
NetRX2_1: RX2.1, T2.3
NetT3_3: T3.3, TX1.1
NetT4_3: T4.3, TX2.1
Nettf1_1: USD1.23, tf1.1
Nettf1_2: USD1.22, tf1.2
Nettf1_5: USD1.19, tf1.5
Nettf1_7: USD1.18, tf1.7
Nettf1_8: USD1.16, tf1.8
OTG_CLK: R42.1, U1.A11
OTG_DATA0: U1.A14, U4.3
OTG_DATA1: U1.D15, U4.4
OTG_DATA2: U1.A12, U4.5
OTG_DATA3: U1.F12, U4.6
OTG_DATA4: U1.C16, U4.7
OTG_DATA5: U1.A10, U4.9
OTG_DATA6: U1.E13, U4.10
OTG_DATA7: U1.C18, U4.13
OTG_DIR: U1.C13, U4.31
OTG_NXT: U1.E16, U4.2
OTG_RESETN: C121.2, R33.1, U1.D16, U4.27
OTG_STP: U1.C15, U4.29
PG_1V0: R7.2, U6.4, U7.13
PG_1V5: R13.2, U8.4, U9.13
PG_1V8: R8.2, U7.4, U8.13
PHY_AD0/LED0: R31.1, R46.2, U3.35
PHY_AD1/LED1: R32.1, R40.2, U3.34
PHY_MDI0_N: LG1.P3, U3.2
PHY_MDI0_P: LG1.P2, U3.1
PHY_MDI1_N: LG1.P7, U3.5
PHY_MDI1_P: LG1.P4, U3.4
PHY_MDI2_N: LG1.P6, U3.8
PHY_MDI2_P: LG1.P5, U3.7
PHY_MDI3_N: LG1.P9, U3.11
PHY_MDI3_P: LG1.P8, U3.10
PMEB: R35.2, U3.33
PS_CLK_500: R37.1, U1.E7
PS_MIO7: R56.2, U1.D8
PS_MIO8: R47.2, U1.D5
PS_PRO_B: U1.C7, U3.29, U13.2
QSPI_CS: *.1, R59.1, U1.A7
QSPI_D0: *.5, R49.2, U1.B8
QSPI_D1: *.2, R51.2, U1.D6
QSPI_D2: *.3, R52.2, U1.B7
QSPI_D3: *.7, R50.2, U1.A6
QSPI_SCK: R53.2, R58.2, U1.A5
REG_OUT: L6.1, U3.48
RFGND: C17.1, C18.1, C20.1, C21.1, C22.1, C23.1, C25.1, C26.1, C27.1, C28.1, C58.2, C59.1, C60.2, C63.1, C142.2, C143.1, C144.1, C145.1, C146.1, C150.1, C151.1, C166.2, C170.2, C172.2, C174.2, C175.2, C177.2, CP1.1, CP3.1, Ct1.2, Ct2.2, R24.2, R25.2, R75.2, RP1.2, RX1.2, RX1.3, RX1.4, RX1.5, RX2.2, RX2.3, RX2.4, RX2.5, RX5.1, RX6.1, RX7.1, RX8.1, RX10.1, RX13.1, RX14.1, RX15.1, RX22.1, T1.1, T1.2, T1.5, T2.1, T2.2, T2.5, T3.1, T3.2, T3.5, T4.1, T4.2, T4.5, TX1.2, TX1.3, TX1.4, TX1.5, TX2.2, TX2.3, TX2.4, TX2.5, U5.A1, U5.A2, U5.A4, U5.A5, U5.A6, U5.A12, U5.B1, U5.B2, U5.B12, U5.C1, U5.C2, U5.C7, U5.C8, U5.C9, U5.C10, U5.C11, U5.C12, U5.D1, U5.D12, U5.E1, U5.F1, U5.F3, U5.F7, U5.F9, U5.F11, U5.G1, U5.G12, U5.H2, U5.H3, U5.H5, U5.H6, U5.H7, U5.H10, U5.J2, U5.K1, U5.K2, U5.K12, U5.L1, U5.L2, U5.L3, U5.L7, U5.L8, U5.L9, U5.L10, U5.L11, U5.L12, U5.M4, U5.M5, U5.M6, U11.0, U11.4, U12.0, U12.4, UP1.2, X4.2
RX1AN_N: C16.1, T1.6
RX1AN_P: C30.1, T1.4
RX1A_N: C16.2, U5.M2
RX1A_P: C30.2, U5.M1
RX1BN_N: C29.1, T2.6
RX1BN_P: C31.1, T2.4
RX1B_N: C29.2, U5.J1
RX1B_P: C31.2, U5.H1
RX_D0_N: U1.P20, U5.K11
RX_D0_P: U1.N20, U5.J12
RX_D1_N: U1.W20, U5.K10
RX_D1_P: U1.V20, U5.J11
RX_D2_N: U1.U20, U5.K9
RX_D2_P: U1.T20, U5.J10
RX_D3_N: U1.R18, U5.K8
RX_D3_P: U1.T17, U5.J9
RX_D4_N: U1.P19, U5.K7
RX_D4_P: U1.N18, U5.J8
RX_D5_N: U1.R17, U5.J7
RX_D5_P: U1.R16, U5.H8
RX_FRAME_N: U1.V13, U5.G7
RX_FRAME_P: U1.U13, U5.G8
SD_CD: R70.2, R71.1, U1.B14
SD_CLK: R72.2, U1.D14
SD_CMD: U1.C17, USD1.4
SD_D0: U1.E12, USD1.6
SD_D1: U1.A9, USD1.7
SD_D2: U1.F13, USD1.1
SD_D3: U1.B15, USD1.3
SPI_CLK: U1.P18, U5.J5
SPI_DI: U1.P15, U5.J4
SPI_DO: U1.P16, U5.L6
SPI_ENB: U1.N17, U5.K6
TEST/ENABLE: RX5.2, U1.J20, U5.C4
TX1AN_N: C48.2, T4.6
TX1AN_P: C40.2, T4.4
TX1A_N: C48.1, L9.2, U5.M8
TX1A_P: C40.1, L8.2, U5.M7
TX1BN_N: C47.2, T3.6
TX1BN_P: C32.2, T3.4
TX1B_N: C47.1, L7.2, U5.M10
TX1B_P: C32.1, L5.2, U5.M9
TXNRX: U1.R14, U5.H4
TX_D0_N: U1.T10, U5.E7
TX_D0_P: U1.T11, U5.F8
TX_D1_N: U1.Y17, U5.D7
TX_D1_P: U1.Y16, U5.E8
TX_D2_N: U1.U12, U5.D8
TX_D2_P: U1.T12, U5.E9
TX_D3_N: U1.Y19, U5.D9
TX_D3_P: U1.Y18, U5.E10
TX_D4_N: U1.W13, U5.D10
TX_D4_P: U1.V12, U5.E11
TX_D5_N: U1.Y14, U5.D11
TX_D5_P: U1.W14, U5.E12
TX_FRAME_N: RX10.2, U1.W16, U5.H9
TX_FRAME_P: U1.V16, U5.G9
UART_RX: P2.11, U1.C12
UART_TX: P2.12, U1.B12
USB2_5V: C137.1, J2.1, P2.15, R64.2, R66.1, R67.1
USB3320_CLK: R76.1, U4.26
USB_ID: J2.4, U4.23
USB_OTG_N: J2.2, P2.17, U4.19
USB_OTG_P: J2.3, P2.16, U4.18
USB_VBUS: R66.2, U4.22
USR_BTN: R19.2, U1.C5, USR_BTN.2
USR_LED: Q2.1, R65.1, U1.C8
VCC1P8: C143.2, C144.2, CP2.1, CP3.2, LP1.2, RP2.1, U5.H12, X4.4
VCC_1V0: C2.2, C33.2, C34.2, C35.2, C36.2, C37.2, C38.2, C39.2, C49.2, C50.2, C51.2, C52.2, C53.2, C57.2, C67.2, L1.2, R7.1, R9.1, U1.G7, U1.G11, U1.G13, U1.H10, U1.H12, U1.J7, U1.J13, U1.K12, U1.L7, U1.L13, U1.M12, U1.N7, U1.N13, U1.P8, U1.P12, U1.R7, U1.R13, U6.14
VCC_1V5: C8.2, C81.1, C98.1, C99.1, C100.1, C101.1, C102.1, C103.1, C104.1, C105.1, C106.1, C107.1, C108.1, C159.2, C160.2, C161.2, C187.2, C188.2, C189.2, C190.2, C191.2, C192.2, C193.2, L3.2, R3.1, R4.2, R13.1, R14.1, U1.A3, U1.D2, U1.E5, U1.G1, U1.H4, U1.L3, U1.P2, U1.R5, U1.U1, U1.V4, U2.A1, U2.A8, U2.B2, U2.C1, U2.C9, U2.D2, U2.D9, U2.E9, U2.F1, U2.G7, U2.H2, U2.H9, U2.K2, U2.K8, U2.N1, U2.N9, U2.R1, U2.R9, U8.14
VCC_1V8: C3.2, C61.2, C62.2, C68.2, C69.2, C70.2, C71.2, C72.2, C73.2, C74.2, C80.2, C82.2, C83.2, C85.2, C86.2, C87.2, C89.2, C90.2, C91.2, C96.2, C109.2, C110.2, C122.1, C141.1, L2.2, R8.1, R10.1, R23.1, R29.2, R30.1, R33.2, R34.1, R39.2, R41.2, R43.2, R45.2, R71.2, U1.A13, U1.B16, U1.C19, U1.D12, U1.E15, U1.F8, U1.F11, U1.F18, U1.G9, U1.H8, U1.H14, U1.J9, U1.J11, U1.J17, U1.K8, U1.K20, U1.L11, U1.M8, U1.M16, U1.N9, U1.N11, U1.N19, U1.P10, U1.R9, U1.R15, U1.T8, U1.T18, U1.U11, U1.V14, U1.W7, U1.W17, U1.Y10, U1.Y20, U3.15, U3.21, U4.8, U4.11, U4.14, U4.28, U4.30, U4.32, U7.14, USD1.5, X3.1, X3.4
VCC_3V3: *.8, C9.2, C20.2, C21.2, C25.2, C26.2, C75.2, C76.2, C77.2, C78.2, C113.2, C114.2, C115.2, C116.2, C120.1, C132.1, C133.1, C134.1, C138.1, C139.1, C181.1, C182.1, C183.1, CP1.2, DONE.1, L4.2, LG1.14, P2.1, P2.6, R15.1, R16.1, R19.1, R27.2, R35.1, R38.1, R46.1, R47.1, R48.1, R55.1, R57.1, R59.2, R63.1, R68.2, U1.B6, U1.D7, U1.K6, U1.M6, U1.N6, U1.R6, U1.T6, U3.6, U3.37, U3.38, U3.41, U3.44, U3.45, U4.21, U9.14, U11.5, U11.7, U11.8, U12.5, U12.7, U12.8, U13.4, UP1.1, UP1.4, USD1.17, USD1.21, USR_LED.1, X2.1, X2.4, tf1.4
VCC_IN: C4.2, C5.2, C10.2, C12.2, P2.13, P2.14, TU1.5, U6.10, U6.11, U6.12, U6.13, U7.10, U7.11, U7.12, U8.10, U8.11, U8.12, U9.10, U9.11, U9.12
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

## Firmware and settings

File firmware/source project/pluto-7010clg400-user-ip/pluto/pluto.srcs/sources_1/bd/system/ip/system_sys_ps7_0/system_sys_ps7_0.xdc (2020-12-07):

############################################################################
##
##  Xilinx, Inc. 2006            www.xilinx.com
############################################################################
##  File name :       ps7_constraints.xdc
##
##  Details :     Constraints file
##                    FPGA family:       zynq
##                    FPGA:              xc7z010clg400-1
##                    Device Size:        xc7z010
##                    Package:            clg400
##                    Speedgrade:         -1
##
##
############################################################################
############################################################################
############################################################################
# Clock constraints                                                        #
############################################################################
create_clock -name clk_fpga_1 -period "5" [get_pins "PS7_i/FCLKCLK[1]"]
set_input_jitter clk_fpga_1 0.15
#The clocks are asynchronous, user should constrain them appropriately.#
create_clock -name clk_fpga_0 -period "10" [get_pins "PS7_i/FCLKCLK[0]"]
set_input_jitter clk_fpga_0 0.3
#The clocks are asynchronous, user should constrain them appropriately.#


############################################################################
# I/O STANDARDS and Location Constraints                                   #
############################################################################

#  GPIO / gpio[53] / MIO[53]
set_property iostandard "LVCMOS18" [get_ports "MIO[53]"]
set_property PACKAGE_PIN "C11" [get_ports "MIO[53]"]
set_property slew "slow" [get_ports "MIO[53]"]
set_property drive "8" [get_ports "MIO[53]"]
set_property pullup "TRUE" [get_ports "MIO[53]"]
set_property PIO_DIRECTION "BIDIR" [get_ports "MIO[53]"]
#  GPIO / gpio[52] / MIO[52]
set_property iostandard "LVCMOS18" [get_ports "MIO[52]"]
set_property PACKAGE_PIN "C10" [get_ports "MIO[52]"]
set_property slew "slow" [get_ports "MIO[52]"]
set_property drive "8" [get_ports "MIO[52]"]
set_property pullup "TRUE" [get_ports "MIO[52]"]
set_property PIO_DIRECTION "BIDIR" [get_ports "MIO[52]"]
#  GPIO / gpio[51] / MIO[51]
set_property iostandard "LVCMOS18" [get_ports "MIO[51]"]
set_property PACKAGE_PIN "B9" [get_ports "MIO[51]"]
set_property slew "slow" [get_ports "MIO[51]"]
set_property drive "8" [get_ports "MIO[51]"]
set_property pullup "TRUE" [get_ports "MIO[51]"]
set_property PIO_DIRECTION "BIDIR" [get_ports "MIO[51]"]
#  GPIO / gpio[50] / MIO[50]
set_property iostandard "LVCMOS18" [get_ports "MIO[50]"]
set_property PACKAGE_PIN "B13" [get_ports "MIO[50]"]
set_property slew "slow" [get_ports "MIO[50]"]
set_property drive "8" [get_ports "MIO[50]"]
set_property pullup "TRUE" [get_ports "MIO[50]"]
set_property PIO_DIRECTION "BIDIR" [get_ports "MIO[50]"]
#  UART 1 / rx / MIO[49]
set_property iostandard "LVCMOS18" [get_ports "MIO[49]"]
set_property PACKAGE_PIN "C12" [get_ports "MIO[49]"]
set_property slew "slow" [get_ports "MIO[49]"]
set_property drive "8" [get_ports "MIO[49]"]
set_property pullup "TRUE" [get_ports "MIO[49]"]
set_property PIO_DIRECTION "INPUT" [get_ports "MIO[49]"]
#  UART 1 / tx / MIO[48]
set_property iostandard "LVCMOS18" [get_ports "MIO[48]"]
set_property PACKAGE_PIN "B12" [get_ports "MIO[48]"]
set_property slew "slow" [get_ports "MIO[48]"]
set_property drive "8" [get_ports "MIO[48]"]
set_property pullup "TRUE" [get_ports "MIO[48]"]
set_property PIO_DIRECTION "OUTPUT" [get_ports "MIO[48]"]
#  GPIO / gpio[47] / MIO[47]
set_property iostandard "LVCMOS18" [get_ports "MIO[47]"]
set_property PACKAGE_PIN "B14" [get_ports "MIO[47]"]
set_property slew "slow" [get_ports "MIO[47]"]
set_property drive "8" [get_ports "MIO[47]"]
set_property pullup "TRUE" [get_ports "MIO[47]"]
set_property PIO_DIRECTION "BIDIR" [get_ports "MIO[47]"]
#  USB Reset / reset / MIO[46]
set_property iostandard "LVCMOS18" [get_ports "MIO[46]"]
set_property PACKAGE_PIN "D16" [get_ports "MIO[46]"]
set_property slew "slow" [get_ports "MIO[46]"]
set_property drive "8" [get_ports "MIO[46]"]
set_property pullup "TRUE" [get_ports "MIO[46]"]
set_property PIO_DIRECTION "OUTPUT" [get_ports "MIO[46]"]
#  GPIO / gpio[45] / MIO[45]
set_property iostandard "LVCMOS18" [get_ports "MIO[45]"]
set_property PACKAGE_PIN "B15" [get_ports "MIO[45]"]
set_property slew "slow" [get_ports "MIO[45]"]
set_property drive "8" [get_ports "MIO[45]"]
set_property pullup "TRUE" [get_ports "MIO[45]"]
set_property PIO_DIRECTION "BIDIR" [get_ports "MIO[45]"]
#  GPIO / gpio[44] / MIO[44]
set_property iostandard "LVCMOS18" [get_ports "MIO[44]"]
set_property PACKAGE_PIN "F13" [get_ports "MIO[44]"]
set_property slew "slow" [get_ports "MIO[44]"]
set_property drive "8" [get_ports "MIO[44]"]
set_property pullup "TRUE" [get_ports "MIO[44]"]
set_property PIO_DIRECTION "BIDIR" [get_ports "MIO[44]"]
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

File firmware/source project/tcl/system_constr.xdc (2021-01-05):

# constraints
# ad9361 (SWAP == 0x1)
set_property BITSTREAM.CONFIG.UNUSEDPIN Pullnone [current_design]
set_property  -dict {PACKAGE_PIN  U18  IOSTANDARD LVCMOS18 } [get_ports rx_clk_in]
set_property  -dict {PACKAGE_PIN  U13  IOSTANDARD LVCMOS18 } [get_ports rx_frame_in]
set_property  -dict {PACKAGE_PIN  P20  IOSTANDARD LVCMOS18 } [get_ports rx_data_in[0]]
set_property  -dict {PACKAGE_PIN  N20  IOSTANDARD LVCMOS18 } [get_ports rx_data_in[1]]
set_property  -dict {PACKAGE_PIN  W20  IOSTANDARD LVCMOS18 } [get_ports rx_data_in[2]]
set_property  -dict {PACKAGE_PIN  V20  IOSTANDARD LVCMOS18 } [get_ports rx_data_in[3]]
set_property  -dict {PACKAGE_PIN  U20  IOSTANDARD LVCMOS18 } [get_ports rx_data_in[4]]
set_property  -dict {PACKAGE_PIN  T20  IOSTANDARD LVCMOS18 } [get_ports rx_data_in[5]]
set_property  -dict {PACKAGE_PIN  R18  IOSTANDARD LVCMOS18 } [get_ports rx_data_in[6]]
set_property  -dict {PACKAGE_PIN  T17  IOSTANDARD LVCMOS18 } [get_ports rx_data_in[7]]
set_property  -dict {PACKAGE_PIN  P19  IOSTANDARD LVCMOS18 } [get_ports rx_data_in[8]]
set_property  -dict {PACKAGE_PIN  N18  IOSTANDARD LVCMOS18 } [get_ports rx_data_in[9]]
set_property  -dict {PACKAGE_PIN  R17  IOSTANDARD LVCMOS18 } [get_ports rx_data_in[10]]
set_property  -dict {PACKAGE_PIN  R16  IOSTANDARD LVCMOS18 } [get_ports rx_data_in[11]]

set_property  -dict {PACKAGE_PIN  T16  IOSTANDARD LVCMOS18} [get_ports tx_clk_out]
set_property  -dict {PACKAGE_PIN  V16  IOSTANDARD LVCMOS18} [get_ports tx_frame_out]
set_property  -dict {PACKAGE_PIN  W14  IOSTANDARD LVCMOS18} [get_ports tx_data_out[0]]
set_property  -dict {PACKAGE_PIN  Y14  IOSTANDARD LVCMOS18} [get_ports tx_data_out[1]]
set_property  -dict {PACKAGE_PIN  V12  IOSTANDARD LVCMOS18} [get_ports tx_data_out[2]]
set_property  -dict {PACKAGE_PIN  W13  IOSTANDARD LVCMOS18} [get_ports tx_data_out[3]]
set_property  -dict {PACKAGE_PIN  Y18  IOSTANDARD LVCMOS18} [get_ports tx_data_out[4]]
set_property  -dict {PACKAGE_PIN  Y19  IOSTANDARD LVCMOS18} [get_ports tx_data_out[5]]
set_property  -dict {PACKAGE_PIN  T12  IOSTANDARD LVCMOS18} [get_ports tx_data_out[6]]
set_property  -dict {PACKAGE_PIN  U12  IOSTANDARD LVCMOS18} [get_ports tx_data_out[7]]
set_property  -dict {PACKAGE_PIN  Y16  IOSTANDARD LVCMOS18} [get_ports tx_data_out[8]]
set_property  -dict {PACKAGE_PIN  Y17  IOSTANDARD LVCMOS18} [get_ports tx_data_out[9]]
set_property  -dict {PACKAGE_PIN  T11  IOSTANDARD LVCMOS18} [get_ports tx_data_out[10]]
set_property  -dict {PACKAGE_PIN  T10  IOSTANDARD LVCMOS18} [get_ports tx_data_out[11]]

set_property  -dict {PACKAGE_PIN  V17  IOSTANDARD LVCMOS18} [get_ports gpio_status[0]]
set_property  -dict {PACKAGE_PIN  T14  IOSTANDARD LVCMOS18} [get_ports gpio_status[1]]
set_property  -dict {PACKAGE_PIN  T15  IOSTANDARD LVCMOS18} [get_ports gpio_status[2]]
set_property  -dict {PACKAGE_PIN  P14  IOSTANDARD LVCMOS18} [get_ports gpio_status[3]]
set_property  -dict {PACKAGE_PIN  U14  IOSTANDARD LVCMOS18} [get_ports gpio_status[4]]
set_property  -dict {PACKAGE_PIN  U15  IOSTANDARD LVCMOS18} [get_ports gpio_status[5]]
set_property  -dict {PACKAGE_PIN  T19  IOSTANDARD LVCMOS18} [get_ports gpio_status[6]]
set_property  -dict {PACKAGE_PIN  V18  IOSTANDARD LVCMOS18} [get_ports gpio_status[7]]

set_property  -dict {PACKAGE_PIN  G20  IOSTANDARD LVCMOS18} [get_ports gpio_ctl[0]]
set_property  -dict {PACKAGE_PIN  D20  IOSTANDARD LVCMOS18} [get_ports gpio_ctl[1]]
set_property  -dict {PACKAGE_PIN  F20  IOSTANDARD LVCMOS18} [get_ports gpio_ctl[2]]
set_property  -dict {PACKAGE_PIN  H20  IOSTANDARD LVCMOS18} [get_ports gpio_ctl[3]]

set_property  -dict {PACKAGE_PIN  W19  IOSTANDARD LVCMOS18} [get_ports gpio_en_agc]
set_property  -dict {PACKAGE_PIN  R19  IOSTANDARD LVCMOS18} [get_ports gpio_resetb]

set_property  -dict {PACKAGE_PIN  V15  IOSTANDARD LVCMOS18} [get_ports enable]
set_property  -dict {PACKAGE_PIN  R14  IOSTANDARD LVCMOS18} [get_ports txnrx]

set_property  -dict {PACKAGE_PIN  J16  IOSTANDARD LVCMOS18 PULLTYPE PULLUP} [get_ports iic_scl]
set_property  -dict {PACKAGE_PIN  K16  IOSTANDARD LVCMOS18 PULLTYPE PULLUP} [get_ports iic_sda]

set_property  -dict {PACKAGE_PIN  N17  IOSTANDARD LVCMOS18  PULLTYPE PULLUP} [get_ports spi_csn]
set_property  -dict {PACKAGE_PIN  P18  IOSTANDARD LVCMOS18} [get_ports spi_clk]
set_property  -dict {PACKAGE_PIN  P15  IOSTANDARD LVCMOS18} [get_ports spi_mosi]
set_property  -dict {PACKAGE_PIN  P16  IOSTANDARD LVCMOS18} [get_ports spi_miso]

set_property  -dict {PACKAGE_PIN  L15  IOSTANDARD LVCMOS18} [get_ports gpio_bd]
set_property  -dict {PACKAGE_PIN  W18  IOSTANDARD LVCMOS18} [get_ports clk_out]


set_property  -dict {PACKAGE_PIN  L16  IOSTANDARD LVCMOS18} [get_ports pl_spi_clk_o]
set_property  -dict {PACKAGE_PIN  L17  IOSTANDARD LVCMOS18} [get_ports pl_spi_miso]
set_property  -dict {PACKAGE_PIN  K17  IOSTANDARD LVCMOS18} [get_ports pl_spi_mosi]


create_clock -name rx_clk -period  16.27 [get_ports rx_clk_in]

# probably gone in 2016.4
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

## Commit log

2020-11-10 第一次提交
    第一次提交
    [01 ZYNQ_DDR.SchDoc, 02 ZYNQ_PS-BANK500-501.SchDoc, 03 ZYNQ_PL-BANK34-35.SchDoc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]
2020-11-10 修改了3.3V网络标号错误
    修改了3.3V网络标号错误，去掉一些退耦电容
    [02 ZYNQ_PS-BANK500-501.SchDoc, 04 ZYNQ_BANK0.SchDoc, 06 ZYNQ_POWER.SchDoc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]
2020-11-11 修改了射频覆铜
    修改了射频覆铜
    [01 ZYNQ_DDR.SchDoc, 05 POWER-SUPPLY.SchDoc, 06 ZYNQ_POWER.SchDoc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]
2020-11-11 更新了README
    更新了README
2020-11-11 更新bom和阻值标注
    [05 POWER-SUPPLY.SchDoc, ZYNQ7010_AD9363.xlsx]
2020-11-12 添加丝印和焊盘泪滴
2020-11-17 提交固件工程，重新设计文件目录
    [01 ZYNQ_DDR.SchDoc, 02 ZYNQ_PS-BANK500-501.SchDoc, 03 ZYNQ_PL-BANK34-35.SchDoc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]
2020-11-17 sdk代码
2020-11-19 更新readme
2020-11-20 修改ddr连接
    [01 ZYNQ_DDR.SchDoc, ZYNQ7010_AD9363.PrjPcb]
2020-11-20 修改射频部分
    [01 ZYNQ_DDR.SchDoc, 03 ZYNQ_PL-BANK34-35.SchDoc, 07 AD9363.SchDoc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]
2020-11-30 修改lvds走线
    [01 ZYNQ_DDR.SchDoc, 02 ZYNQ_PS-BANK500-501.SchDoc, 03 ZYNQ_PL-BANK34-35.SchDoc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]
2020-12-02 更新布线
    [01 ZYNQ_DDR.SchDoc, 03 ZYNQ_PL-BANK34-35.SchDoc, 06 ZYNQ_POWER.SchDoc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]
2020-12-05 最新布线2r2t
    [01 ZYNQ_DDR.SchDoc, 03 ZYNQ_PL-BANK34-35.SchDoc, 04 ZYNQ_BANK0.SchDoc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]
2020-12-07 更新丝印
    [ZYNQ7010_AD9363.PrjPcb]
2020-12-07 更新 README
2020-12-07 后续修改
    [ZYNQ7010_AD9363.PrjPcb]
2020-12-07 更新固件
2020-12-12 删除错误图纸
2020-12-23 添加pluto-sdr二进制固件
2020-12-30 更新pcb设计
    [02 ZYNQ_PS-BANK500-501.SchDoc, 04 ZYNQ_BANK0.SchDoc, 05 POWER-SUPPLY.SchDoc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]
2021-01-05 更新tcl脚本
2021-01-14 update hardware
    [PcbLib1.PcbLib]
